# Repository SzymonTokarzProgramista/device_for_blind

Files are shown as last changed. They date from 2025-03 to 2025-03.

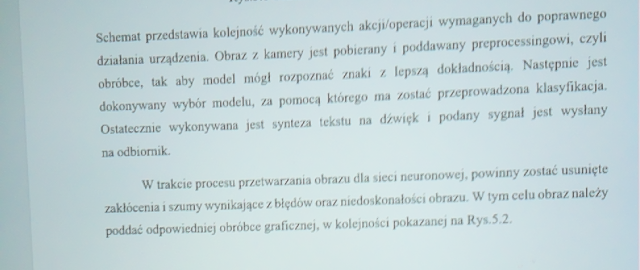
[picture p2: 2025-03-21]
inzynierka/obrona.png

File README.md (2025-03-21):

# device_for_blind
This device is designed to assist visually impaired individuals by recognizing printed characters and converting them into accessible formats (e.g., audio feedback). The system uses a camera to capture text in the environment, then processes the image using two machine learning models for character recognition.

The first model is a custom Convolutional Neural Network (CNN) trained from scratch for basic character classification. The second model leverages ResNet50 with transfer learning, allowing for more accurate and robust recognition, especially in more complex or noisy environments.

By combining these two models, the device ensures both speed and high accuracy in real-time character detection. It is intended to support independence for visually impaired users by helping them interpret written information in their daily lives.

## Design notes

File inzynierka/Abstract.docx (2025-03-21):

Abstract

In his paper, the author described the process of developing the device, starting with presenting the design of the tool. Then the operation of image processing was described, where the various possible filtering and segmentation methods were analyzed and the one that gave the best results was selected. Later, the construction of neural networks was discussed, and it was explained how the model using the author's neural network and the model using ResNet 50 learned with Transfer Learning works. It is also described how both models were implemented on the Raspberry Pi platform along with sound synthesis. Functional tests of the device's performance under various conditions depending on the angle at which the image was taken and the lighting were performed. The author has fulfilled all the objectives outlined in the scope of work, including preparing the design of the case for the device and printing it.

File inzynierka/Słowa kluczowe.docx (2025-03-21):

Słowa kluczowe:

Binaryzacja, filtr Wienera, segmentacja oparta na liniach konturowych, konwolucyjne sieci neuronowe, Transfer learning, rozpoznawanie tekstu, Raspberry Pi, druk 3D, ResNet50, bezprzewodowa komunikacja, Bluetooth, synteza tekstu na dźwięk

Keywords:

Binarization, Wiener filter, contour line based segmentation, convolutional neural networks, Transfer learning, text recognition, Raspberry Pi, 3D printing, ResNet50, wireless communication, Bluetooth, text to sound synthesis

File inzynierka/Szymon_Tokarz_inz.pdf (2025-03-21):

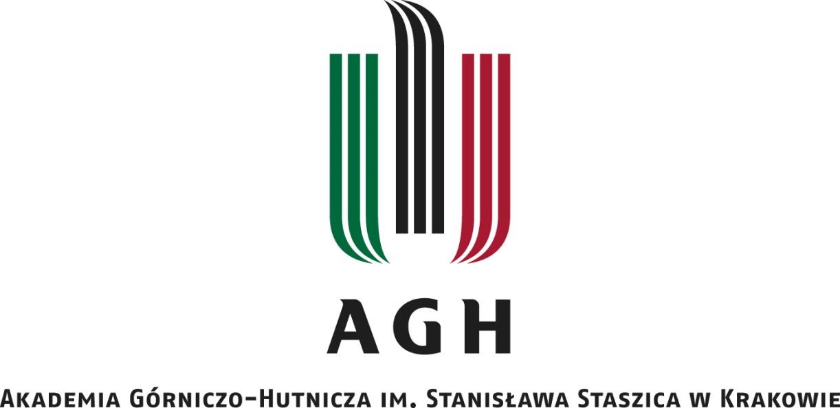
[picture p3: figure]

1

––

WYDZIAŁ ELEKTROTECHNIKI, AUTOMATYKI, INFORMATYKI I INŻYNIERII BIOMEDYCZNEJ

## Projekt dyplomowy

## System wizyjny do odczytu materiałów drukowanych wspomagający osoby niewidzące A vision system for reading printed materials supporting blind people

Autor: | Szymon Tokarz
Kierunek studiów: | Automatyka i Robotyka
Opiekun pracy: | dr inż. Maciej Rosół

Kraków, 2025

2

## Oświadczenie

Świadomy odpowiedzialności karnej za poświadczanie nieprawdy oświadczam, że niniejszą

inżynierską pracę dyplomową wykonałem/łam osobiście i samodzielnie oraz nie

korzystałem/łam ze źródeł innych niż wymienione w pracy.

Jednocześnie oświadczam, że dokumentacja oraz praca nie narusza praw autorskich

w rozumieniu ustawy z dnia 4 lutego 1994 roku o prawie autorskim i prawach pokrewnych

(Dz. U. z 2006 r. Nr 90 poz. 631 z późniejszymi zmianami) oraz dóbr osobistych chronionych

prawem cywilnym. Nie zawiera ona również danych i informacji, które uzyskałem/łam

w sposób niedozwolony.

Zaświadczam także, że niniejsza inżynierska praca dyplomowa nie była wcześniej podstawą

żadnej innej urzędowej procedury związanej z nadawaniem dyplomów wyższej uczelni lub

tytułów zawodowych.

3

## Spis treści

4

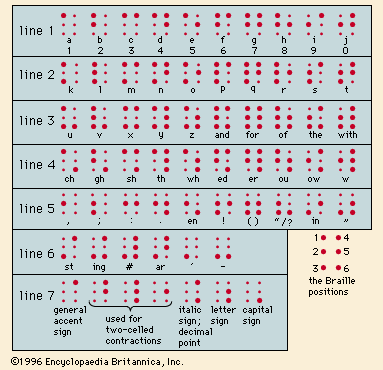
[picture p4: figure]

5

# Rozdział 1 Wstęp [2]

Na przestrzeni ostatnich kilkudziesięciu lat pojawiały się najróżniejsze rozwiązania

mające na celu pomoc osobom niewidzącym w czytaniu. Zdecydowanie najbardziej

popularnym i rozpowszechnionym jest alfabet Braille’a, który wspiera w codziennym życiu

wiele osób niepełnosprawnych. Zastąpienie typowych liter alfabetu zestawem wypukłych

punktów przez Louis Braille’a w 1821 roku umożliwiło niewidomym czytanie i było

największym skokiem w historii ich edukacji. Sam system jest uproszczeniem kodu

wojskowego wymyślonego przez Charlesa Barbiera, który pozwalał na komunikację w nocy

pomiędzy oficerami. Alfabet Braille’a, przedstawiony na rysunku 1.1, składa się z 63 znaków

obejmujących maksymalnie 6 wypukłych kropek ustawionych w macierzy 3x2.

Rys.1.1 Alfabet Braille’a [2]

## 1.1 Cel Pracy

Celem pracy jest projekt i praktyczna realizacja systemu wizyjnego do rozpoznawania

liter i cyfr w języku polskim i angielskim z drukowanych materiałów, służącego jako pomoc

dla osób niewidomych. Rozpoznane litery i słowa będą następnie przekształcane na sygnał

dźwiękowy, który może zostać odsłuchany przez te osoby. Urządzenie to wraz

z oprogramowaniem powinno być łatwe oraz intuicyjne w użyciu.

6

## 1.2 Zakres pracy

Zakres pracy obejmuje zaprojektowanie oraz wykonanie sieci neuronowej służącej

do rozpoznawanie znaków drukowanych, a następnie przekształcenie rozpoznanego ciągu

znaków na sygnał dźwiękowy z możliwością jego odsłuchania. Zadana sieć neuronowa jest

jednokierunkowa oraz może mieć maksymalnie 2 warstwy wewnętrzne. Oczekuje się

przeprowadzania porównania między własnoręczną siecią neuronową, a gotowym modelem,

który za pomocą metody Transfer Learningu został nauczony rozpoznawać znaki. Całe

urządzenie będzie osadzone w obudowie, która zostanie zaprojektowana oraz wydrukowana

przez autora.

Rozdział 1 opisuje podstawowe założenia oraz cele pracy dyplomowej. Opisane są

również przewidywane wyniki pracy dyplomowej, cele i zakres pracy.

W rozdziale 2 autor porusza temat rynku istniejących rozwiązań sprzętowo-

programowych dla osób niewidomych oraz prezentuje wybrane dostępne produkty.

Rozdział 3 opisuje założenia projektowe. Autor przedstawia w nim wybrane podzespoły

wykorzystane w projekcie oraz pokazuje jego wstępną logikę. Autor przedstawia wykonany

przez niego projekt obudowy wraz z koniecznymi rysunkami technicznymi i modelami 3D.

Rozdział 4 wyjaśnia zagadnienia związane z uczeniem maszynowym, które są

wykorzystane w pracy oraz omawia ich zastosowanie.

Rozdział 5 jest poświęcony przygotowaniu obrazu. Autor opisuje i porównuje wybrane

metody filtracji i segmentacji, które mogą zostać wykorzystane w projekcie oraz wybiera

optymalną opcję.

Rozdział 6 jest poświęcony budowie przygotowanej sieci neuronowej oraz wykonanej

bazie danych. Autor porusza w nim tematy z zakresu rodzajów warstw w konwolucyjnych

sieciach neuronowych oraz przytacza wartości hiperparametrów. Opisuje również model

ResNet 50 wykorzystany do Transfer Learningu oraz omawia, jakie modyfikacje zostały

wprowadzone do tej sieci.

W rozdziale 7 przedstawione są rezultaty uzyskane za pomocą obydwóch modeli oraz

zostało przeprowadzone porównanie tych wyników. Autor omawia w nim wady i zalety

wykorzystanych sieci w kontekście problemu opisywanego w pracy.

7

Rozdział 8 omawia etapy złożenia oraz połączenia wszystkich części projektu

opisywanych w pracy. Przedstawione zostają metody implementacji projektu oraz syntezy

tekstu na mowę.

Rozdział 9 opisuje aplikację wykonaną w celu ułatwienia testowania urządzenia.

Poruszane są w nim treści z zakresu narzędzi użytych do tworzenia GUI oraz zalety jego

stworzenia. Przedstawione są testy funkcjonalne urządzenia, które mają na celu sprawdzenie

poprawności działania w różnych warunkach.

8

# Rozdział 2 Przegląd istniejących rozwiązań

Obecnie na rynku istnieje kilka interesujących rozwiązań wspomagających czytanie

i rozumienie tekstu osobom niewidomym, jednak każde z nich ma swoje wady i zalety.

Narzędzia rozpoznające tekst powinna cechować duża dokładność oraz możliwość

identyfikacji znaków drukowanych jak i pisma ręcznego. Problem z dokładnym

sklasyfikowaniem konkretnych liter i cyfr pisma ręcznego sprawia różnorodność charakterów

pisma i nie tylko, ponieważ znaczenie ma również nawet kolor długopisu i strony, który może

powodować zaburzenia odczytu przez urządzenie. Kolejnym ważnym czynnikiem jest cena

produktu. Osoby niepełnosprawne, w tym ludzie niewidomi, mają ograniczony budżet

związany ze swoją przypadłością, więc kwota, którą powinni zapłacić za urządzenie nie

powinna być duża. Jednak z mniejszą ceną naturalnie wiąże się gorsza jakość części

hardware’u, takich jak kamera bądź skaner. Użycie gorszego sprzętu oznacza również

zmniejszoną dokładność rozpoznawania znaków. Z tych względów rynek narzędzi

rozpoznających tekst jest dosyć zróżnicowany.

## 2.1 LyriQ Text-to-Speech Reader [1]

Urządzenie firmy Zyrlo (Rys.2.1), w odróżnieniu od narzędzia wykonanego przez

autora, wykorzystuje skaner w celu zwiększenia dokładności rozpoznawania tekstu. Użycie

skanera powoduje, że LyriQ jest dosyć sporym i relatywnie ciężkim obiektem. Waży około

1,3 kg (3 lbs), ma możliwość złożenia na płasko, co faktycznie ułatwia transport. Najbardziej

odstraszającym czynnikiem w samym produkcie jest niewątpliwie cena, która mieści się w

granciach 2300 – 2500 $, czyli w przeliczeniu na polską walutę to około 9200 – 10000 zł.

Dodatkowo trzeba wziąć pod uwagę koszty wysyłki. Wysoka cena jest spowodowana jakością

produktu. LyriQ Text-to-Speech Reader błyskawicznie rozpoczyna czytanie i jest intuicyjny

w użyciu. Urządzenie wykorzystuje sztuczną inteligencję – Lyriq AI, która jest w stanie

rozpoznać pismo odręczne jak również materiały drukowane takie jak rachunki czy paragony.

Dzięki użyciu skanera dokładność urządzenia Lyriq wynosi około 98%. Posiada także

możliwość skanowania kodów kreskowych. Urządzenie ma możliwość czytania w 20 różnych

językach, domyślnie zainstalowano angielski i hiszpański.

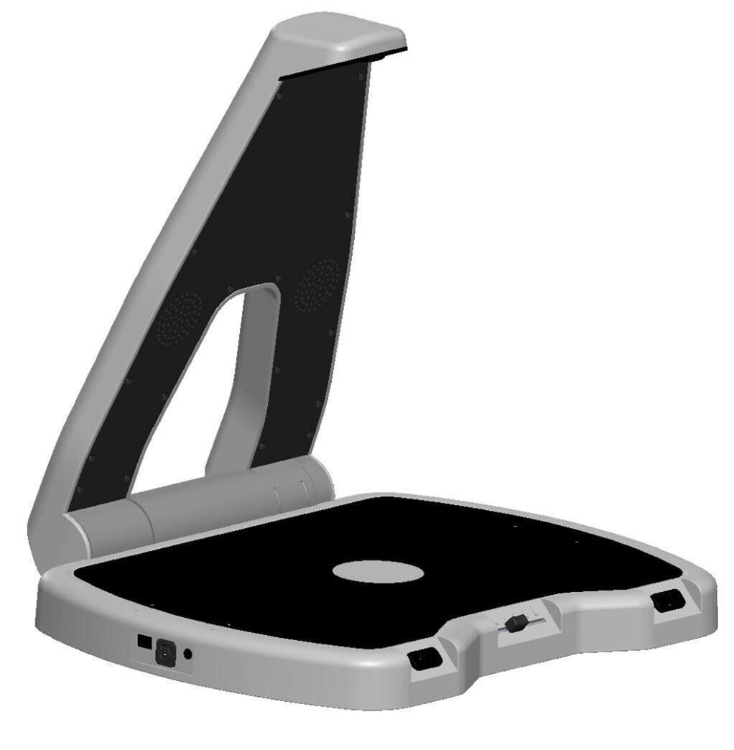
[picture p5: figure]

9

Rys.2.1 Urządzenie LyriQ [1]

## 2.2 Envision Low Vision Glasses [3]

Ciekawym rozwiązaniem są okulary firmy Envision (Rys.2.2). Zaprojektowane z myślą

o komforcie użytkownika, okulary poza rozpoznawaniem teksu zostały wyposażone w szereg

różnych funkcji, takich jak, rozpoznawanie kolorów, skanowanie dokumentów, czy nawet

rozpoznawanie ludzi. Urządzenie zostało zaprojektowane na podstawie Google Glass

Enterprise Edition 2 oraz wyposażone w lekkie tytanowe oprawki. Największą zaletą produktu

firmy Envision jest jego wygoda. Samo urządzenie można zamówić w różnych opcjach, które

oczywiście mają inne ceny w zależności od wyposażonych funkcji. Najbardziej podstawowa

wersja okularów Envsion kosztuje około 8 500 zł. Okulary firmy Envision wykorzystują

sztuczną inteligencję zapewnianą przez Google. Pozwala ona na rozpoznanie tekstu

z dokładnością 95% - 99% w dobrych warunkach oświetleniowych. Urządzenie ma nawet

możliwość połączenia z Chatem GPT-4. Wykorzystano w nim kamerę 8MP z 80º polem

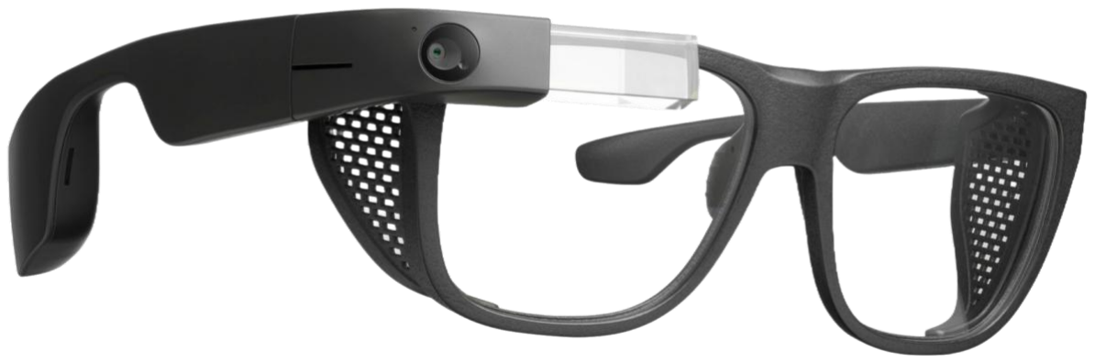
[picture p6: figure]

10

widzenia, które przetwarza obrazy w czasie rzeczywistym, co pozwala na dokładne

rozpoznanie tekstu.

Rys.2.2 Envision Low Vision Glasses [3]

## 2.3 Text to Speech (TTS) [4]

Bardzo popularnym rozwiązaniem jest użycie Text to Speech (TTS). Jest to rozszerzenie

wyprodukowane przez Google wykorzystujące sztuczną inteligencję tej samej firmy.

Wykorzystanie tej wtyczki jest bardzo proste, wystarczy mieć telefon i zrobić zdjęcie strony.

Google zapewnia możliwość czytania w ponad 50 językach operujących na różnych alfabetach.

Narzędzie ma również opcję wyboru lektora. Wtyczka sprawia, że użytkownikowi wystarczy

telefon komórkowy, aby pomóc osobie niewidomej. Google TTS wykorzystuje technologię

WaveNet, stworzoną przez firmę DeepMind, do generacji dźwięku z bardzo naturalnym

brzmieniem.

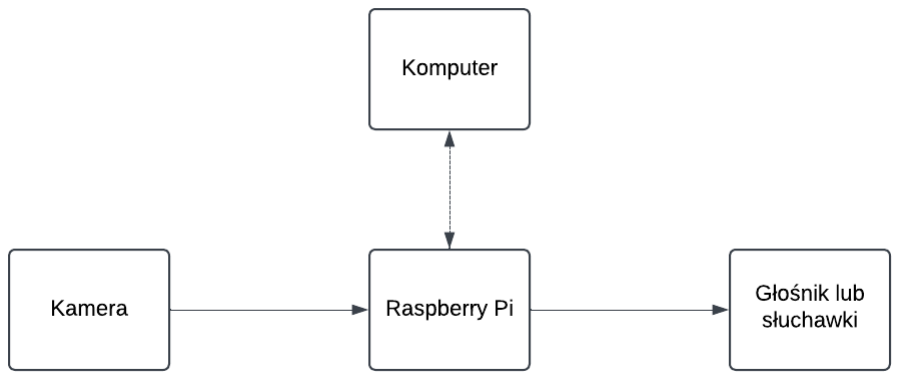
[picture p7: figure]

11

# Rozdział 3 Projekt urządzenia

Jak wspomniano we wstępie, zaproponowane urządzenie wspomagające osoby

niewidzące powinno być tanie i zapewniać prostotę użytkowania. Stąd założenia projektowe

koncentrują się na ogólnodostępnych, budżetowych komponentach. Schemat blokowy

przedstawiający koncepcję budowy urządzenia przedstawiono na Rys.3.1. Zawiera on

minikomputer Raspberry Pi, kamerę, wyjście audio do podłączenia głośników lub słuchawek

oraz komputer klasy PC.

Rys.3.1 Poglądowy schemat blokowy urządzenia

Obraz będzie pobierany z kamery i przesłany na platformę Raspberry Pi, gdzie zostanie

przetworzony oraz klasyfikowany. Raspberry Pi zostanie połączone bezprzewodowo

za pomocą sieci WiFi z komputerem osobistym, gdzie będzie można zobaczyć podgląd

z kamery oraz dokonać wyboru, który typ modelu wykorzystać do klasyfikacji. Rozpoznany

tekst zostanie przekonwertowany na dźwięk i wysłany, za pomocą Bluetooth, do głośnika lub

słuchawek.

## 3.1 Raspberry Pi 4B

Do wykonania urządzenia autor zdecydował się na użycie minikomputera Raspberry Pi

4B (Rys.3.2) ze względu na jego kompaktowość oraz niski koszt. Dodatkową zaletą jest

również możliwość wykorzystania narzędzi w środowisku Matlab/Simulink takich jak,

np. MATLAB Support Package for Raspberry Pi Hardware, które są kompatybilne z platformą

Raspberry Pi i bardzo ułatwiają programowanie urządzenia. Wykorzystano system operacyjny

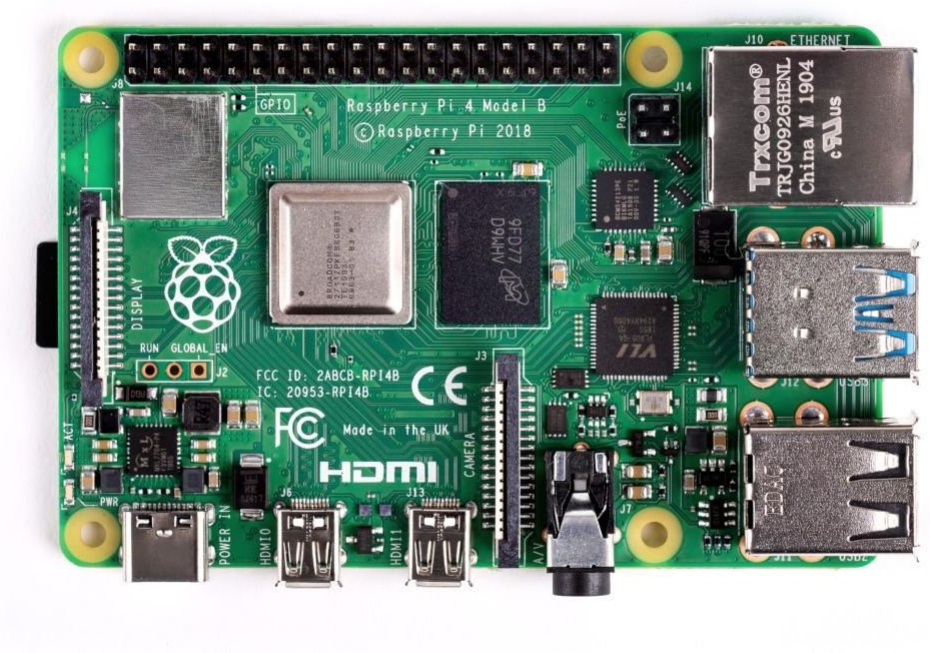
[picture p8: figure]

12

Raspberry Pi OS w wersji bookworm. W tabeli 3.1 zawarto specyfikację techniczną użytej

platformy sprzętowej.

Tabela 3.1 Podstawowe parametry techniczne Raspberry Pi 4B [22]

Procesor | Cortex-A72
Liczba rdzeni | 4
Liczba portów USB 3.0 | 2
Liczba portów USB 2.0 | 2
Liczba portów Gigabit Ethernet | 1
Bluetooth | 5.0
Zasilanie | 5V/3A
RAM | 4GB

Rys.3.2 Raspberry Pi 4B [22]

13

## 3.2 Kamera 5MP OV5647

Do akwizycji obrazów z drukowanych dokumentów tekstowych wybrano kamerę 5MP

OV5647 (Rys.3.3) ze względu na kompatybilność z platformą Raspberry Pi 4B oraz wysoką

jakość obrazu w porównaniu do ceny. Dane techniczne użytej kamery są widoczne w tabeli 3.2.

Tabela 3.2 Dokumentacja kamery 5MP OV5647 [23]

Liczba MP | 5
Aktywne piksele | 2592x1944
Tryby wideo | 1080p30,720p60,640x480p60/90
Ogniskowa | 3,60 mm
FoV | 54x41
Rozmiar piksela | 1,4µm x 1,4µm

Rys.3.3 Kamera 5MP OV5647 [23]

## 3.3 Projekt obudowy

Komponenty użyte do budowy urządzenia zostały umieszczone w zaprojektowanej

obudowie. Na tym etapie użyto program Inventor Professional 2025 firmy Autodesk.

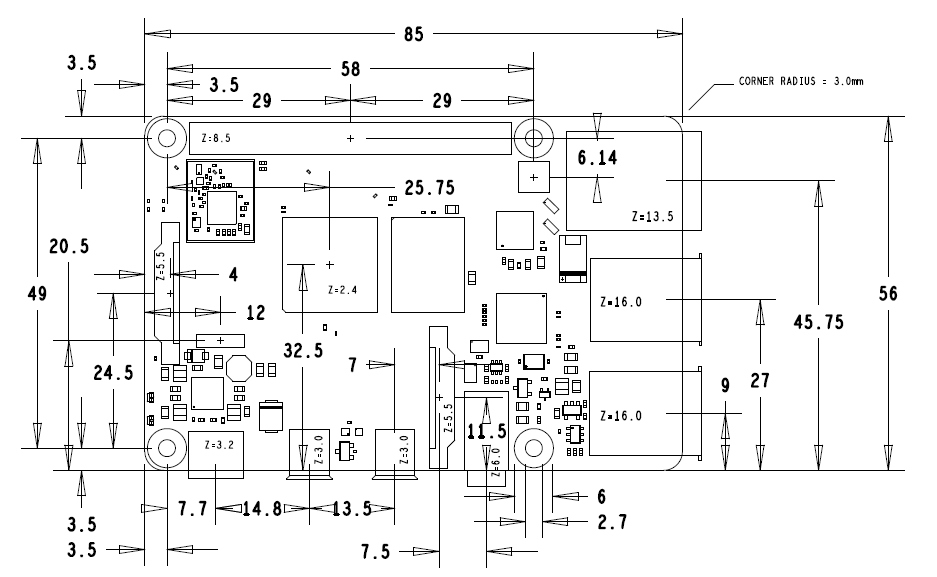
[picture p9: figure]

14

Wykonano w nim model 3D obudowy, który później został użyty do druku 3D. Cała obudowa

składa się z części górnej i dolnej, które zostały połączone śrubami M2,6. Do projektu obudowy

wykorzystano gotowy model 3D Raspberry Pi 4B, który został pobrany ze strony GrabCad

(Rys.3.4) (Rys.3.5).

Rys.3.4 Rysunek techniczny modelu Raspberry Pi 4B [20]

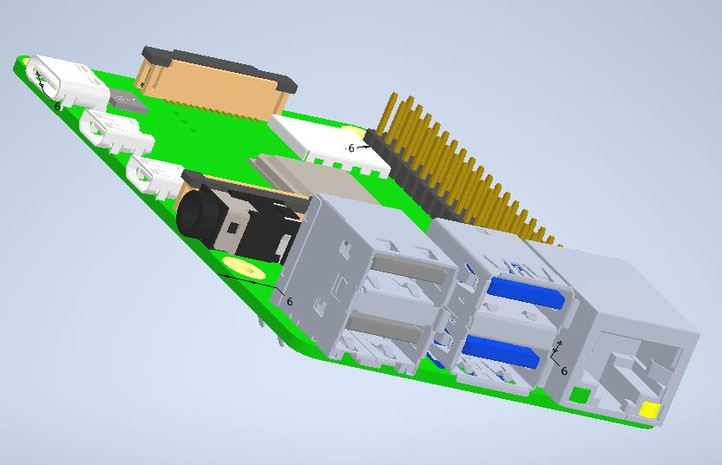
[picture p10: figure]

15

Rys.3.5 Model 3D Raspberry Pi 4B [20]

Po zapoznaniu się z modelem Raspberry Pi i upewnieniu się, że wymiary są poprawne

rozpoczęto projektowanie części obudowy. Wykonane modele części górnej i dolnej wraz

z rysunkami technicznymi (uwzględniającymi model złożeniowy) przedstawiono odpowiednio

na Rys.3.6 i Rys.3.7.

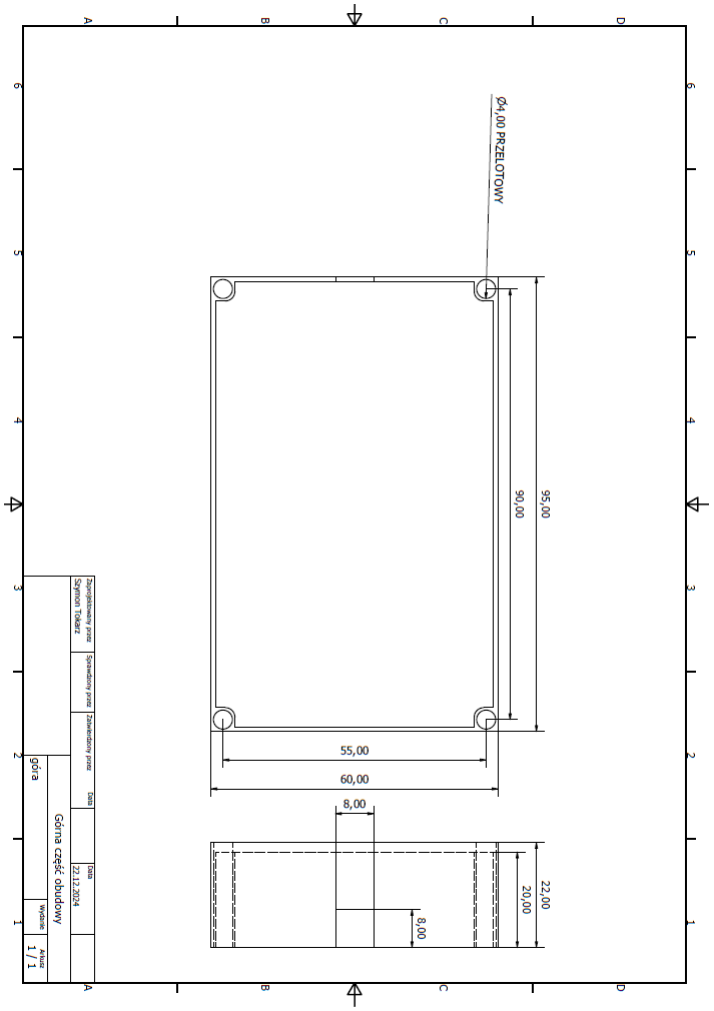
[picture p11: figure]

16

Rys.3.6 Rysunek techniczny górnej części obudowy

17

Rys.3.7 Rysunek techniczny dolnej części obudowy

18

## 3.4 Komputer

W celu wykonania projektu należało wykorzystać komputer osobisty, który został użyty

do zaprogramowania minikomputera Raspberry Pi oraz do przeprowadzenia testów

funkcjonalnych urządzenia. Do napisania kodu programu, obsługującego urządzenie,

wykorzystano głównie środowisko Matlab/Simulink 2024b wraz z następującymi

przybornikami:

- Audio Toolbox,
- Computer Vision Toolbox,
- Deep Learning Toolbox,
- Image Processing Toolbox,

oraz dodatkowe pakiety sprzętowe (ang. Hardware Package) służące do obsługi Raspberry Pi:

- Matlab Support Package For Raspberry Pi Hardware,
- Simulink Support Package For Raspberry Pi Hardware.

W celu stworzenia bazy danych, gromadzącej dane potrzebne do nauki sieci neuronowej, użyto

języka Python 3.9. Jako środowisko rozwojowe tego języka wykorzystano IDE PyCharm

2023.2.2.

Komputer zostanie połączony przez sieć WiFi z urządzeniem i będzie odpowiedzialny

za wybór rodzaju modelu do rozpoznawania tekstu. Stworzona będzie również aplikacja, na

której zostanie wyświetlony aktualny obraz z kamery.

19

# Rozdział 4 Zagadnienia uczenia maszynowego

Uczenie maszynowe (ang. Machine Learning) to dział sztucznej inteligencji, który

polega na tym, że komputery mogą zbierać wiedzę z danych i na ich podstawie rozpoznawać

wzorce [11]. Rozpoznaje się dwa główne rodzaje uczenia maszynowego: nadzorowane

i nienadzorowane. Różnica pomiędzy nimi polega na tym, że w uczeniu nadzorowanym dane

są etykietowane, a w nienadzorowanym nie. Taki zabieg sprawia, że uczenie nadzorowane jest

dokładniejsze i szybsze w treningu, za to przy uczeniu nienadzorowanym można

wykorzystywać niepełne bazy danych.

W uczeniu maszynowym można wykorzystać najróżniejsze algorytmy. Najbardziej

popularne to:

- algorytmy regresyjne,
- algorytmy wykorzystujące drzewa decyzyjne,
- algorytm Bayesa,
- sieci neuronowe.

W dalszej części tego rozdziału zostaną omówione podstawowe zagadnienia, takie jak sieci

neuronowe i Transfer Learning, które to zostały wykorzystane w projekcie.

## 4.1 Sieć neuronowa [7]

„System przeznaczony do przetwarzania informacji, którego budowa i zasada działania

są w pewnym stopniu wzorowane na funkcjonowaniu fragmentów rzeczywistego

(biologicznego) systemu nerwowego. Na przesłankach biologicznych oparte są schematy

sztucznych neuronów wchodzących w skład sieci oraz (w pewnym stopniu) jej struktura.

Jednak schematy połączeń neuronów w sieci neuronowej są wybierane arbitralnie, a nie

stanowią modelu rzeczywistych struktur nerwowych.” [8]

W | kontekście | rozpoznawania | znaków | drukowanych, | sieci neuronowe | są

wykorzystywane już od prawie 30 lat. Pierwszymi, którzy je zastosowali byli Rost i Kwatra

[5][6]. Wytrenowali swoje sieci w celu rozpoznawania angielskich samogłosek. Od tego

momentu informatykom z całego świata udało się zaprogramować sieci neuronowe

20

rozpoznające takie języki jak mandaryński, mongolski, urdu lub nawet staro-cerkiewno-

słowiański z bardzo dużą dokładnością.

Najbardziej popularne sieci neuronowe służące do OCR (ang. Optical Character

Recognition) są kilkuwarstwowe z propagacją wsteczną. Zgodnie z pozycją [8] „Propagacja

wsteczna opiera się na koncepcji poprawiania na każdym kroku procesu uczenia wartości

korekty wag na podstawie oceny błędu popełnianego przez każdy neuron podczas uczenia

sieci”.

## 4.2 Transfer Learning [9]

Transfer Learning jest techniką wykorzystywaną w Machine Learningu polegającą

na ponownym użyciu modelu do zwiększenia jakości lub szybkości rozwiązania dla podobnego

zadania. Definicja brzmi następująco:

Dla dziedziny źródła Ds i zadania uczącego Ts, dziedzina celu Dt i zadania uczącego Tt,

Transfer Learning ma na celu poprawę efektów uczenia funkcji przewidywania celu ft (·)

w dziedzinie Dt wykorzystując wiedzę w dziedzinie Ds i zadaniu Ts, gdzie Ds ≠ Dt oraz

Ts ≠ Tt.[9][10]

W swojej pracy Pan i Yang dzielą Transfer Learning na 3 rodzaje (Tabela 4.1):

- indukcyjny,
- nienadzorowany,
- transdukcyjny.

Tabela 4.1 Rodzaje Transfer Learningu [9]

Ustawienia uczenia | Dziedzina źródła i celu | Zadanie źródła i celu
Tradycyjny Machine Learning | Taka sama | Takie same
Transfer Learning | Indukcyjny | Taka sama | Inne, ale spokrewnione
| Nienadzorowany | Inna, ale spokrewniona | Inna, ale spokrewnione
| Transdukcyjny | Inna, ale spokrewniona | Takie same

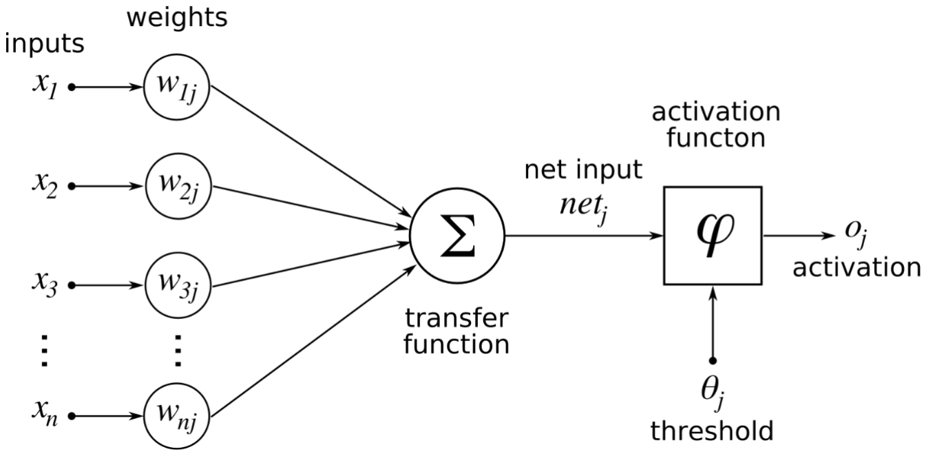
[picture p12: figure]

21

Obecnie Transfer Learning jest wykorzystywany głównie przy analizie tekstu oraz

obrazów ze względu na łatwość w implementacji, jakość prezentowanych rozwiązań oraz brak

potrzeby dużej bazy danych. Kolejną zaletą Transfer Learningu jest fakt, że istnieje szeroki

wachlarz wytrenowanych sieci neuronowych, które można wykorzystać jako źródło.

## 4.3 Konwolucyjne sieci neuronowe (CNN) [24]

Konwolucyjna sieć neuronowa jest przykładem sieci typu feed forward, co oznacza, że dane

przepływają tylko w jednym kierunku. Typowe sieci CNN składają się z różnych rodzajów

warstw, jak np.:

- warstwa konwolucji,
- warstwa aktywacji,
- warstwa poolingu,
- warstwa w pełni połączona (ang. fully connected layer).

Sieć CNN składa się z połączenia kilku warstw konwolucyjnych, po których znajduje się

warstwa poolingu powtórzona kilkukrotnie. Na samym końcu znajduje się warstwa w pełni

połączona. Architekturę takiej sieci przedstawiono na rysunku 4.1. Dokładny opis

poszczególnych warstw sieci CNN, wykorzystanej w pracy, znajduje się w rozdziale 6.

Rys.4.1 Schemat sieci konwolucyjnej [25]

22

# Rozdział 5 Proces przetwarzania obrazu

Program uruchamiany na platformie Raspberry Pi uwzględnia wszystkie etapy

od pobrania obrazu z kamery do syntezy dźwięku na podstawie rozpoznanego tekstu. Schemat

blokowy logiki programu przedstawiono na Rys.5.1.

Rys.5.1 Schemat blokowy logiki programu

Schemat przedstawia kolejność wykonywanych akcji/operacji wymaganych do poprawnego

działania urządzenia. Obraz z kamery jest pobierany i poddawany preprocessingowi, czyli

obróbce, tak aby model mógł rozpoznać znaki z lepszą dokładnością. Następnie jest

dokonywany wybór modelu, za pomocą którego ma zostać przeprowadzona klasyfikacja.

Ostatecznie wykonywana jest synteza tekstu na dźwięk i podany sygnał jest wysłany

na odbiornik.

W trakcie procesu przetwarzania obrazu dla sieci neuronowej, powinny zostać usunięte

zakłócenia i szumy wynikające z błędów oraz niedoskonałości obrazu. W tym celu obraz należy

poddać odpowiedniej obróbce graficznej, w kolejności pokazanej na Rys.5.2.

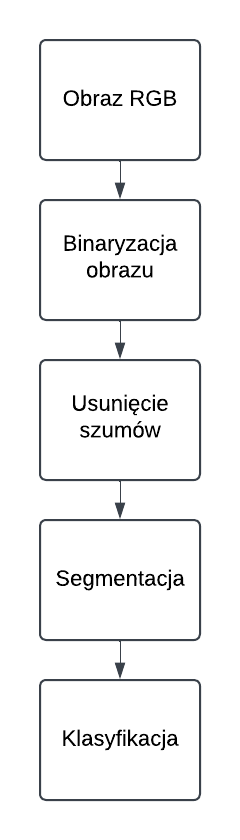
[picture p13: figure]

23

Rys.5.2 Schemat blokowy dla przetwarzania obrazów

Najpierw obraz RGB musi zostać poddany binaryzacji, czyli konwersji do reprezentacji

czarno-białej. Następnym etapem jest usunięcie szumów. Proces polega na analizie obrazu

binarnego i znalezieniu pikseli, które nie pasują do ich otoczenia. Na Rys.5.3 widać,

że kilkanaście pikseli nie należy do liter, ale istnieją w obrazie. Piksele te trzeba usunąć,

ponieważ zaburzają klasyfikację sieci neuronowej. Kolejną etapem jest odpowiednia

segmentacja obrazu na poszczególne litery. Ostatnim krokiem jest klasyfikacja obrazu

do odpowiedniej litery.

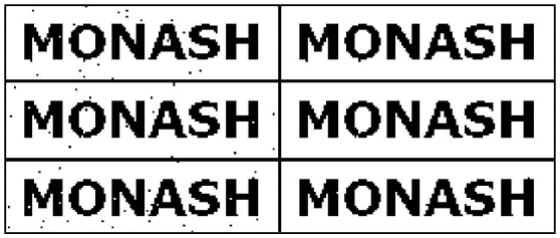
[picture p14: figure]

24

Rys.5.3 Przykład usuwania szumów [7]

## 5.1 Obraz RGB i binaryzacja

Urządzenie jest obsługiwane przez kamerę o rozdzielczości 5 MP, więc obraz może być

nieznacznie zamazany. W tym celu, aby uzyskać jak najlepszą binaryzację całego obrazu, autor

najpierw przekształca go do odcieni szarości, po czym dokonuje korekcji kontrastu (Rys.5.4).

Dzięki temu zabiegowi łatwiej jest dobrać uniwersalny próg binaryzacji, ponieważ różnice

pomiędzy tłem, a tekstem są zdecydowanie większe. Przeprowadzenie binaryzacji jest

konieczne, ponieważ ułatwia analizę obrazu przez sieć neuronową. Użycie tej operacji

zwiększa dokładność i szybkość klasyfikacji.

25

Rys.5.4 Operacje przeprowadzone na obrazie

## 5.2 Filtracja i usuwanie szumów [12]

Po binaryzacji obrazu należy przefiltrować go ze względu na występujące szumy.

W tym celu autor rozważał użycie następujących filtrów:

- filtr uśredniający,
- filtr medianowy,
- filtr Wienera,
- filtr korzystający z operacji morfologicznych.

Filtr uśredniający poprawia wartość piksela na podstawie średniej wartości pikseli

w jego otoczeniu. Rxy reprezentuje sąsiedztwo okna podobrazu o wymiarach m × n, o środku

w punkcie (x, y). Dla poziomu szarości piksela (x, y), filtr zmienia poziom szarości J(x, y)

ze szczegółami otaczającego piksela. Opisuje to równanie:

26

J(x, y) =

1
M ⋅ N

∑ K(u, v)

(u,v)∈Rxy

Filtr medianowy jest nieliniową metodą wykorzystującą wartość mediany wartości

szarości otaczających pikseli. Ten filtr jest w stanie usunąć zaburzenia bez rozmazywania

krawędzi. Mediana jest obliczana po posortowaniu wartości pikseli i wybierana jest z nich

środkowa wartość. Filtr może wybierać różne rozmiary otoczenia, jednak najbardziej popularne

są 3 × 3 lub 5 × 5. Filtr ten jest zdefiniowany równaniem:

J(x, y) = median(u,v)∈Rxy

{K(u, v)}

Filtr Wienera jest przykładem adaptacyjnego filtru, który działa w oparciu

o minimalizację błędu średniokwadratowego (MSE). Jego zaletą jest lepsze działanie niż np.

filtr średniej zwłaszcza w obszarach o zróżnicowanej intensywności, jednak wymaga

większego nakładu czasowego. Równanie opisujące filtr Wienera ma następującą postać:

I

̂(x, y) =

σI

2

σI

2+σN

2

⋅ I(x, y),

gdzie:

- I

̂(x, y): Wyjściowy (oczyszczony) obraz,

- I(x, y): Sygnał wejściowy z szumem,
- σI

2
: Wariancja obrazu oryginalnego,
- σN

2
: Wariancja szumu.

Istnieje również możliwość przefiltrowania obrazu działając wyłącznie na operacjach

morfologicznych. Wymaga to użycia funkcji bwareaopen, która jest dostępna w pakiecie Image

Processing Toolbox programu MATLAB. Ta funkcja znajduje obiekty o rozmiarach zadanych

jako argument i je usuwa. Tę operację należy wykonać na obrazie binarnym oraz trzeba zadać

stały próg wielkości obiektów. Ta metoda jest bardzo użyteczna przy obrazach, na których

występują litery o dużym rozmiarze i nie nachodzą na siebie, ponieważ bezpośrednio usuwa

niechciane artefakty. Wykorzystanie funkcji bwareaopen posiada wadę w postaci długiego

czasu wykonania, spowodowanego skomplikowanym algorytmem.

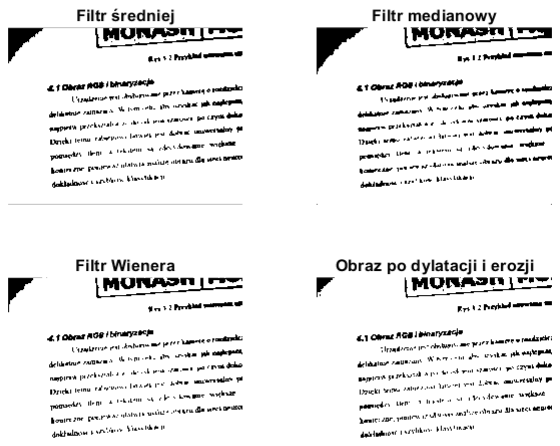
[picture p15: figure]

27

Autor pracy wykonał porównanie rezultatów po filtracji (Rys. 5.5) oraz przeprowadził

testy czasowe w celu wybrania najlepszej opcji dla problemu rozpoznawania znaków

drukowanych.

Rys.5.5 Obrazy po różnych rodzajach filtracji

Z powyższych obrazów można zauważyć, że filtr Wienera daje najlepsze rezultaty

pod względem wyglądu obrazu. Usunął więcej małych artefaktów u góry obrazu, przy czym

nie zniekształcił znacząco liter. Warto zauważyć, że bardzo dobry wynik daje również użycie

funkcji bwareaopen. Przy dużych literach właśnie użycie tej metody najlepiej wyodrębnia

litery. Wyniki testów czasu wykonywania poszczególnych algorytmów filtracji przedstawiono

w Tabeli 5.1.

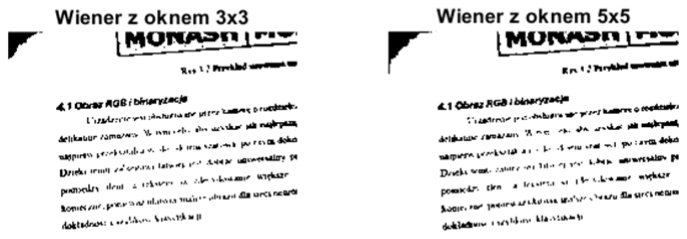
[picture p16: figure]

28

Tabela 5.1 Porównanie testów czasowych

Rodzaj filtru | Średni czas przetwarzania obrazu [s]
Filtr średniej | 0.2673
Filtr medianowy | 0.3246
Filtr Wienera | 0.4625
Funkcja bwareaopen | 3.1932

Czasy potrzebne do przefiltrowania obrazu (Tabela 5.1) są porównywalne dla filtrów

średniej, medianowego i Wienera. Jak przewidywano funkcja bwareaopen zajmuje dużo więcej

czasu, aby wykonać to zadanie. Biorąc pod uwagę testy czasowe oraz dokładność filtracji autor

zdecydował się użyć filtru Wienera.

Należy również dokonać wyboru rozmiaru okna używanego przez filtr Wienera.

Wszystkie poprzednie testy wykonano dla rozmiaru okna 3 × 3 (tak samo, jak dla filtru

medianowego). Analizie poddano trzy rodzaje okien:

- Małe - 3×3, 5×5;
- Średnie - 7×7, 9×9;
- Duże - 15×15, 21×21.

Rys.5.6 Obrazy przy użyciu małych okien dla filtra Wienera

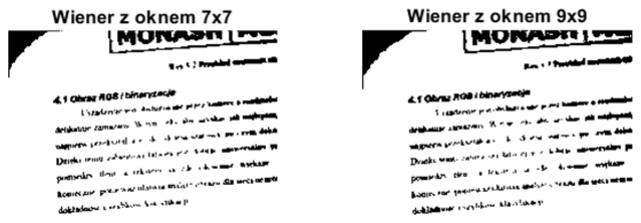
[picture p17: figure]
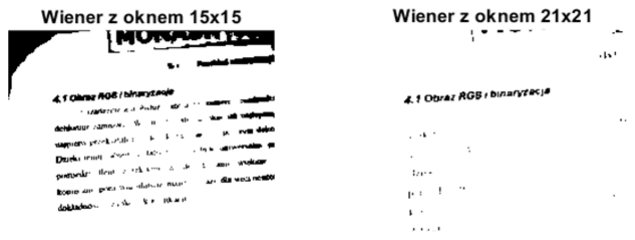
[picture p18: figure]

29

Rys.5.7 Obrazy przy użyciu średnich okien dla filtra Wienera

Rys.5.8 Obrazy przy użyciu dużych okien dla filtra Wienera

Z obrazów przedstawionych na: Rys.5.6, Rys.5.7 i Rys.5.8 można wywnioskować,

że duże okna 15×15 i 21×21, ze względu na swój rozmiar, filtrują zbyt dużą część obrazu.

Z kolei filtry o średnich oknach dobrze usuwają małe obiekty, które nie powinny być poddane

ocenie, ale zbytnio zniekształcają krawędzie liter. Najlepszym rozwiązaniem będzie użycie

okna o wymiarach 5×5, ze względu na lepszą zdolność usuwania niepożądanych szumów niż

okno 3×3 przy zachowaniu odporności na zmianę wyglądu liter.

## 5.3 Segmentacja

Po wstępnej obróbce obrazu należy rozpoznać znajdujący się na nim tekst

z uwzględnieniem podziału na pojedyncze litery, tak aby sieć neuronowa mogła

30

je sklasyfikować. Istnieją różne metody segmentacji, jednak przy rozpoznawaniu tekstu

najbardziej popularne to [26]:

- segmentacja oparta na progowaniu,
- segmentacja oparta na połączeniu pikseli,
- segmentacja oparta na liniach konturowych,
- segmentacja oparta na projekcjach, itd.

Segmentacja oparta na progowaniu jest techniką wykorzystywaną ze względu na swoją

prostotę i łatwość w implementacji, często przy obrazach z małą entropią. Ta metoda dzieli

obraz na regiony na podstawie wartości pikseli w skali szarości. Wartość progu może być

wybrana automatycznie, np. za pomocą funkcji graythresh w środowisku MATLAB, która

wykorzystuje metodę Otsu. Ten algorytm opiera się na wyborze optymalnego progu

na podstawie maksymalizacji wariancji pomiędzy klasami obrazu. Sama metoda może być

zaimplementowana globalnie, gdzie separowane jest tło i cały obraz zostaje podzielony na dwa

regiony. Znacznie bardziej efektywną metodą jest zastosowanie lokalnego progowania, gdzie

progi są wybierane dla poszczególnych części obrazu z wykorzystaniem metody Otsu. Można

również dobrać próg ręcznie.[13]

Algorytm polegający na łączeniu pikseli (ang. Connected Component Labeling) opiera

się na zasadzie mówiącej, że piksele można nazwać połączonymi, gdy spełniają założenia

przylegania albo bliskości piksela. Każdy piksel z połączeniem jest przylegający, ponieważ ma

relację z sąsiadem. Ponadto istnieje także stałość pomiędzy pikselami przylegającymi, która

wynosi 1 jednostkę długości bez żadnego pośrednika. Tą metodę można wykorzystywać przy

obrazach monochromatycznych jak i binarnych. [14]

Segmentacja wykorzystująca detekcję krawędzi polega na analizie zestawu pikseli,

gdzie otaczające go piksele w skali szarości lub zmiany struktury sugerują zmianę regionu.

Krawędź obiektu w obrazie jest odzwierciedlona poprzez różnice w skali szarości, więc

pierwszym krokiem w tym algorytmie jest znalezienie punktów, które utworzą kontur regionu.

Istotą działania tej metody jest wykrywanie nieciągłości w różnych częściach obrazu za pomocą

operatorów różnicowych pierwszego lub drugiego rzędu. [15]

Segmentacja oparta na projekcjach to technika wykorzystująca tzw. „projekcje obrazu”,

czyli sumy wartości pikseli. Ta metoda może wystąpić w dwóch wariantach działający na tej

31

samej zasadzie. Projekcje poziome wykorzystują sumy pikseli z poszczególnych wierszy, za to

projekcje pionowe wykorzystują sumy pojawiające się w kolumnach. Ideą tego algorytmu jest

sprowadzenie informacji do jednowymiarowych profili, które ułatwiają odnalezienie konturów

obiektów. [16]

W ramach pracy wykonano porównanie powyższych metod, w celu wybrania

najlepszego rozwiązania dla poruszanego problemu. Samo porównanie obejmuje jakość

dokonanej segmentacji oraz szybkość działania algorytmu.

Rys.5.9 Segmentacja oparta na progowaniu

Rys.5.10 Segmentacja oparta na łączeniu pikseli

Rys.5.11 Segmentacja oparta na liniach konturowych

Rys.5.12 Segmentacja oparta o projekcje pionowe

Największym problemem w skuteczności działania ww. algorytmów jest fakt, że litery,

w szczególności te małe, mogą nachodzić na siebie, co powoduje, że przy segmentacji często

pojawia się kilka liter w wyodrębnionym fragmencie. Można zaobserwować to zachowanie

przy segmentacji polegającej na progowaniu (Rys.5.9) i łączeniu pikseli (Rys.5.10). Obydwie

metody dają podobne rezultaty, ponieważ wykorzystano w nich do wyznaczenia progu metodę

Otsu. Algorytm używający projekcji (Rys.5.12) nie jest w stanie dobrze podzielić obrazu,

ze względu na jego zbyt słabą jakość i niewielki odstęp pomiędzy literami. Najlepszą

segmentację udało się uzyskać korzystając z algorytmu opartego na liniach konturowych

(Rys.5.11), który poprawnie rozdzielił wszystkie litery w obrazie testowym.

32

Tabela 5.2 Porównanie testów czasowych

Rodzaj segmentacji | Średni czas przetwarzania obrazu [s]
Progowanie | 0.1821
Łączenie pikseli | 0.2075
Linie konturowe | 0.2625
Projekcje | 0.1772

Wyniki czasu wykonania poszczególnych algorytmów segmentacji zebrano

w Tabeli 5.2. Na ich podstawie można stwierdzić, że najlepiej wypadł algorytm

wykorzystujący projekcje, a najgorzej ten oparty o linie konturowe. Jednakże biorąc pod uwagę

dokładność wszystkich metod autor zdecydował się wybrać segmentacje opartą o linie

konturowe.

Przy użyciu tej metody segmentacji należy zadbać o to, aby znaki interpunkcyjne nie

zostały poddane klasyfikacji. Nie wystarczy jedynie nie brać ich pod uwagę jako małych

obiektów, ponieważ w tym wypadku usunięte zostałyby również części znaków „ó”, „ż” oraz

„ź”. W tym celu wykorzystano dylatację, aby połączyć znaki diakrytyczne (np. kropka na „i”)

z resztą litery w jeden region.

33

# Rozdział 6 Klasyfikacja za pomocą sieci neuronowej

Ostatnim etapem rozpoznawania tekstu jest sklasyfikowanie poszczególnych liter oraz

ich połączenie w słowa. Jednakże, aby móc odpowiednio rozpoznać znaki należy przygotować

sieć neuronową. Dokładny opis i definicję, czym jest sieć neuronowa, znajduje się w rozdziale

4.1. W tym rozdziale autor skupi się na opisie budowy, uczenia i testów zaproponowanej sieci

oraz wyjaśni działania wybranych funkcji i parametrów.

## 6.1 Baza danych

W celu wytrenowania sieci neuronowej należało wykorzystać gotową bazę danych lub

przygotować własną. Autor postanowił wykonać samodzielnie bazę danych ze względu na brak

odpowiedniej, która byłaby zgodna z narzuconymi kryteriami. W tym celu przygotowano

skrypt w języku Python, który generował litery polskiego alfabetu i cyfry używając czcionki

Times New Roman, grupował je oraz przygotował osobny plik, gdzie każdy obraz był

skategoryzowany. Zadbano również, aby obrazy były poddane odpowiedniej augmentacji,

co oznacza, że litery były losowo obracane o kąt ± 15º oraz pogrubiane (Rys.6.1). Ten zabieg

sprawia, że zbiór danych jest bardziej zróżnicowany, przez co sieć neuronowa lepiej rozpoznaje

cechy danego obrazu.

Rys.6.1 Przykłady liter z przygotowanej bazy danych

W efekcie podjętych działań uzyskano zbiór 32 znaków (dużych i małych), przy czym

każdy znak alfabetu był reprezentowany w liczbie 5000. Cała baza danych została podzielona

na 3 zbiory:

34

- uczący (80%),
- walidacyjny (10%),
- testowy (10%).

Zbiór uczący był wykorzystany do wytrenowania modelu, walidacyjny do oceny jakości

modelu w trakcie procesu trenowania. Zbiór testowy został użyty po treningu, aby ocenić

ogólną wydajność modelu.

## 6.2 Budowa sieci neuronowej

Do wykonania sieci neuronowej zostało wykorzystane narzędzie Deep Network

Designer, które jest dostępne w Deep Learning Toolbox programu MATLAB. Deep Network

Designer to aplikacja, w której można tworzyć blokowe schematy sieci neuronowych. W tym

celu można wykorzystać gotowe funkcje służące do np. optymalizacji lub normalizacji sieci.

Autor wybrał to narzędzie ze względu na prostotę w obsłudze oraz łatwość implementacji

wybranej struktury sieci neuronowej. Na Rys.6.2 przedstawiono schemat blokowy

zaprojektowanej, konwolucyjnej sieci neuronowej (CNN). Na wejście sieci podawany jest

obraz o wymiarach 28×28 jednokanałowy, czyli binarny. Sama sieć składa się z dwóch warstw

konwolucyjnych, zgodnie z założeniami projektu dyplomowego. Każda warstwa składa się z:

- warstwy normalizacji batcha,
- warstwy aktywacji ReLu,
- warstwy dropout,
- warstwy poolingu 2D.

Warstwa normalizacji batcha jest używana w głębokich sieciach neuronowych ze względu

na przyspieszenie procesu uczenia, stabilizacji gradientów oraz zmniejszenie szansy

na przeuczenie (ang. overfitting). Normalizacja sprawia, że dla każdej partii (ang. batch) każda

cecha ma średnią równą 0 i odchylenie standardowe równe 1, zgodnie z poniższym wzorem:

x̂ =

x − μ
√σ
2 + ϵ

gdzie:

- x̂ to znormalizowana wartość cechy,
- x to pojedyncza wartość wejściowa,

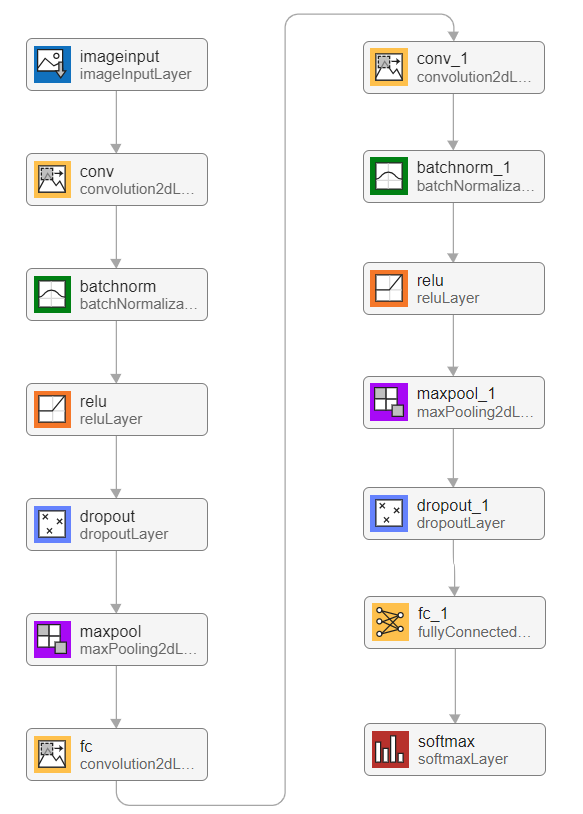
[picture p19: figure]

35

- μ to średnia arytmetyczna wartości wejściowych,
- σ

2
to wariancja wartości wejściowych
- ε to bardzo mała liczba dodawana do mianownika, aby uniknąć dzielenia przez 0.

Rys. 6.2 Schemat blokowy sieci neuronowej

36

Warstwa ReLu (ang. Rectified Linear Unit) to funkcja aktywacji mająca na celu

wprowadzenie nieliniowości, aby model mógł nauczyć się bardziej złożonych zależności. Sama

funkcja jest definiowa jako:

f(x) = max(0, x)

Funkcja ReLu jest bardzo popularna ze względu na łatwość w implementacji, szybkość

działania oraz jest odporna na problem zanikających gradientów.

Warstwa dropout sprawia, że neurony zostają losowo wyłączane, czyli ich wartość

zostaje ustawiana na 0, w celu ograniczenia przeuczenia. Dzięki użyciu tej warstwy sieć nie

polega na zbyt małej liczbie neuronów, przez co model nie jest zależny od pojedynczych cech,

co powoduje lepszą generalizację. Wartość parametru dropout użytego w powyższej sieci

wynosi 0,5, czyli 50% neuronów zostaje wyłączonych.

Warstwa MaxPooling2D pozwala na zmniejszenie wymiarowości danych wejściowych.

Operacja działa na zasadzie maksymalnej selekcji w małych regionach obrazu, czyli wybierana

jest największa wartość w danym oknie. Dzięki tej funkcji model jest w stanie uczyć się

szybciej, przez mniejszą ilość danych oraz jest bardziej odporny na przeuczenie. Wielkość okna

dla funkcji maxPooling2D wynosi 5×5, a krok o jaki przesuwane jest okno to (1,1).

Kluczową częścią wybranej sieci neuronowej są warstwy konwolucyjne, które

odpowiadają za wykrywanie cech. Warstwa konwolucyjna przesuwa filtry, które są małymi

macierzami po całym obrazie. Przy każdym przesunięciu filtr dokonuje operacji splotu, której

wynik jest dodawany do macierzy cech. [17] W pierwszej warstwie przygotowanej sieci

znajdują się 32 filtry o rozmiarze 3×3, które są przesuwane o krok (1,1), natomiast w drugiej

są 64 filtry o wymiarach 5×5, które przemieszczają się z tym samym krokiem. Taki zabieg

powoduje, że model łatwiej jest w stanie rozpoznać bardziej złożone cechy oraz pozwala mu

na bardziej szczegółową analizę danych wejściowych.

Na sam koniec działania sieci dane są analizowane przez warstwę Softmax. Jej zadaniem

jest przekształcanie surowych wyników z wyjścia sieci w rozkład prawdopodobieństwa, który

będzie sumował wartości wszystkich klas do 1. Wzór tej warstwy wygląda następująco:

pi =

e

zi
∑ | e
K | zj
j=1

37

gdzie:

- zi
to logit, czyli surowy wynik, dla klasy i,
- K to liczba klas,
- e

zj
to eksponenta logitu,
- pi prawdopodobieństwo dla klasy i.

Warstwę Softmax wykorzystuje się jako warstwę wyjściową ze względu na możliwość

interpretacji rozkładu prawdopodobieństwa do klasyfikacji obrazu. Na podstawie tej warstwy

można jednoznacznie wskazać, która klasa ma największą szansę na poprawną klasyfikację.

## 6.3 Budowa ResNet50

Istotą Transfer Learningu jest douczenie już wytrenowanej sieci, co dokładniej autor

opisuje w rozdziale 3.2. Kluczowym aspektem staje się wybór odpowiedniej sieci neuronowej.

Autor postanowił wybrać sieć ResNet50 ze względu na jej popularność i zastosowanie

w dziedzinie detekcji obiektów. W środowisku MATLAB istnieje gotowa funkcja rozpoznająca

tekst (ocr ()), która bazuje na silniku Tesseract OCR (open-source), obsługującym ponad 100

języków, w tym polski. Sam silnik jest wspierany przez Google.

ResNet50 to głęboka sieć neuronowa z rodziny Residual Networks, składająca się z 50

warstw konwolucyjnych połączonych za pomocą bloków resztkowych (Rys.6.3). Te bloki

wykorzystują tzw. shortcut connections, co unika problemu zanikającego gradientu,

spowodowanego przez dużą liczbę warstw. Architektura sieci ResNet50 jest podzielona na

4 sekcje:

- warstwy konwolucyjne,
- blok tożsamościowy (ang. identity block),
- blok konwolucyjny,
- w pełni połączone warstwy (ang. fully connected layers).

Warstwy konwolucyjne odpowiadają za ekstrakcje cech z obrazu wejściowego, a bloki

tożsamościowe i konwolucji przetwarzają i przekształcają te cechy. Do klasyfikacji

wykorzystane są w pełni połączone warstwy. [18 - 19]

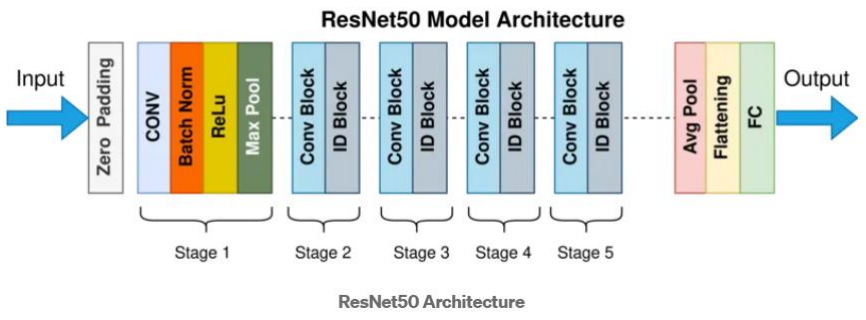
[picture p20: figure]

38

Rys.6.3 Architektura sieci ResNet 50 [19]

Najbardziej kluczowym aspektem sieci z rodziny ResNet jest wykorzystanie tzw.

shortcut connections. Te połączenia pozwalają danym przemieszczać się po sieci

z pominięciem kilku warstw. Ten zabieg umożliwia sieci nauczenie się funkcji resztkowych,

które mapują dane wejściowe, zamiast uczenie się mapowania od zera. Shortcut connections są

używane w blokach konwolucyjnych i tożsamościowych. [19]

## 6.4 Modyfikacja sieci ResNet50

W celu wykorzystania metody Transfer Learningu należało zmodyfikować sieć

ResNet50. Na początku zmodyfikowano dane wejściowe, ponieważ ta sieć wymaga, aby były

one rozmiaru 224×224 oraz wyrażone w kolorach RGB. Po tym zabiegu usunięto ostatnią

warstwę i zastąpiono ją nową, służącą do klasyfikacji, tak aby zgadzała się w niej liczba klas.

Model jest zdecydowanie bardziej skomplikowany niż przygotowana sieć neuronowa

z poprzedniego rozdziału, więc autor zdecydował, aby trenować sieć ustalając mniejszą liczbę

epok.

39

# Rozdział 7 Implementacja programu w Raspberry Pi

Zaimplementowano obydwa modele rozpoznawania tekstu, obsługę kamery oraz

algorytmu przetwarzania obrazu, czyli binaryzację, filtrację oraz segmentację. Cały program

został podzielony na odpowiednie funkcje obsługujące poszczególne zadania.

Ostatnim etapem było zaprogramowanie funkcjonalności, która pozwoli urządzeniu

komunikować się poprzez Bluetooth ze słuchawkami bądź głośnikiem, zaimplementowanie

całego programu na platformę Raspberry Pi oraz złożenie obudowy.

W celu zapewnienia konwersji tekstu na dźwięk użyto najpierw syntezatora mowy

espeak. Narzędzie espeak jest bardzo wygodną opcją ze względu na fakt, że jest darmowe oraz

działa na wielu platformach, w tym na Raspberry Pi. Obsługuje ponad 50 języków i dialektów

oraz ma możliwość dostosowania tempa i tonu głosu. Przygotowano również skrypt

w programie MATLAB, który pozwala na automatyczne parowanie urządzeń z Bluetooth, aby

można było usłyszeć rozpoznawany tekst.

Cały program został podzielony na funkcje, które ułatwiły wykonanie diagramu

blokowego w programie Simulink (Rys.7.1). Jak można zauważyć pierwszym blokiem

w łańcuchu jest blok odczytu obrazu z kamery w formacie RGB. Następnie obraz RGB jest

odczytywany przez blok GUI, gdzie jest przedstawiany użytkownikowi. Użytkownik ma

możliwość zrobienia zdjęcia i wyboru modelu, który przeprowadzi rozpoznawanie tekstu. Gdy

to się wydarzy przeprowadzany jest proces przetwarzania obrazu w bloku preprocessing, gdzie

dokonywana jest filtracja filtrem Wienera oraz segmentacja za pomocą metody używającej linie

konturowe. Zbiór obrazów jest klasyfikowany przez funkcję ocr_1 i ocr_2. Ostatecznie

wykonywana jest konwersja tekstu na dźwięk w bloku speak i następuje wysłanie komunikatu

do urządzenia audio.

Rys.7.1 Schemat blokowy wykonany w Simulinku

40

Na podstawie ww. diagramu wygenerowano kod języka C++, który został przesłany,

skompilowany i uruchomiony na minikomputerze. Użyto do tego przybornika Simulink

Support Package for Raspberry Pi.

Na platformie Raspberry Pi, w celu poprawy wydajności urządzenia, wykorzystano

możliwość użycia większej liczby rdzeni. Dzięki tej metodzie można dokonać równoległej

klasyfikacji obrazów. Wykorzystany minikomputer Raspberry Pi 4B posiada 4 rdzenie, a do

klasyfikacji użyto dwóch. W tym celu zbiór obrazów otrzymanych po segmentacji podzielono

na dwie części. Użyto opcji Concurrent Execution i zmapowano funkcję ocr_1 i ocr_2

do dwóch różnych tasków. Funkcja connect łączy w jeden spójny tekst wyniki klasyfikacji

i zapewnia, że są połączone w odpowiedniej kolejności.

Ostatnim etapem projektu było zamontowanie w obudowie minikomputera Raspberry

Pi wraz z kamerą. Końcowy wygląd urządzenia można zobaczyć na rysunku 7.2.

Rys.7.2 Końcowy wygląd urządzenia

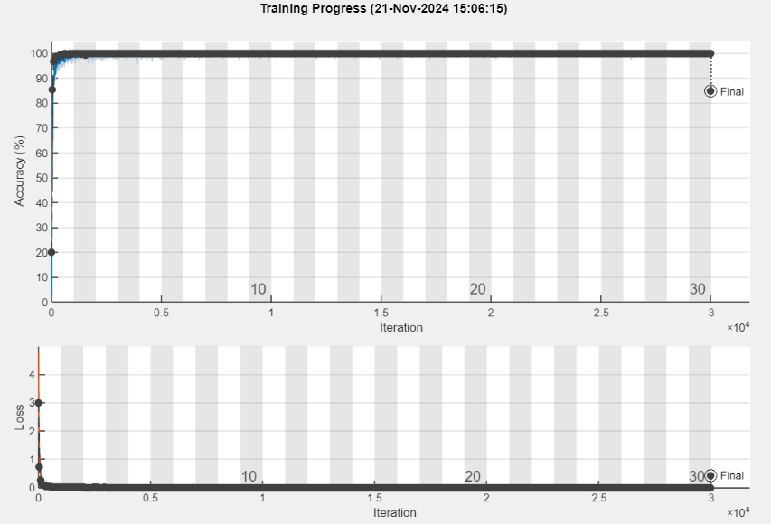
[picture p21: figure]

41

# Rozdział 8 Porównanie wyników

W celu sprawdzenia poprawnego działania dwóch rozwiązań, czyli autorskiej sieci

neuronowej oraz modelu opartego na ResNet50, przeprowadzono testy dokładności

na platformie Raspberry Pi z wykorzystaniem przygotowanej aplikacji. Spodziewanym

rezultatem było uzyskanie lepszych wyników za pomocą douczonej sieci ResNet50 ze względu

na większą liczbę warstw konwolucyjnych.

Po wytrenowaniu dwóch sieci wykonano wykresy obrazujące ich dokładność na zbiorze

walidacyjnym w trakcie procesu uczeniu.

Rys. 8.1 Dokładność przygotowanej sieci

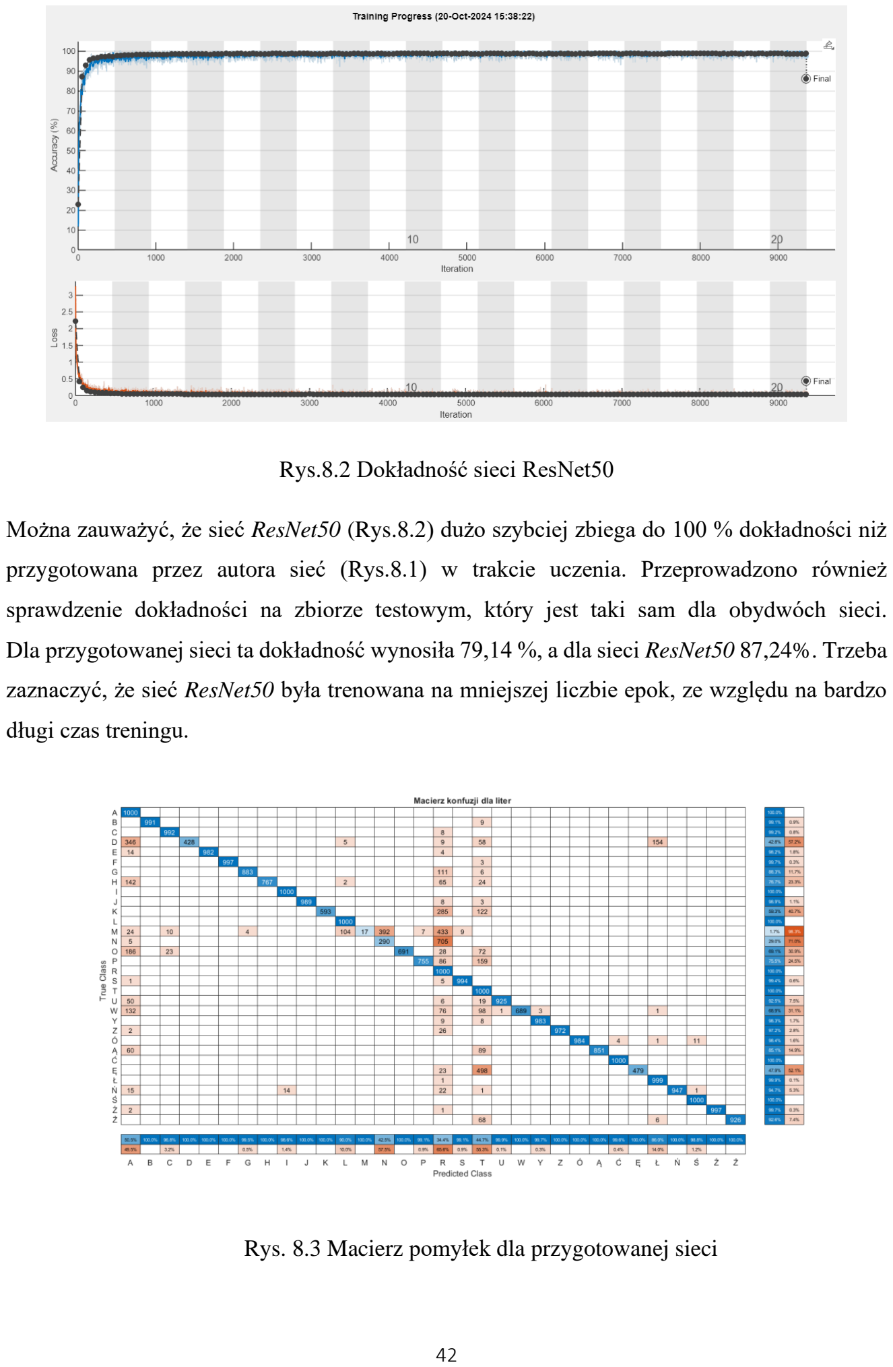
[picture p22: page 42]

42

Rys.8.2 Dokładność sieci ResNet50

Można zauważyć, że sieć ResNet50 (Rys.8.2) dużo szybciej zbiega do 100 % dokładności niż

przygotowana przez autora sieć (Rys.8.1) w trakcie uczenia. Przeprowadzono również

sprawdzenie dokładności na zbiorze testowym, który jest taki sam dla obydwóch sieci.

Dla przygotowanej sieci ta dokładność wynosiła 79,14 %, a dla sieci ResNet50 87,24%. Trzeba

zaznaczyć, że sieć ResNet50 była trenowana na mniejszej liczbie epok, ze względu na bardzo

długi czas treningu.

Rys. 8.3 Macierz pomyłek dla przygotowanej sieci

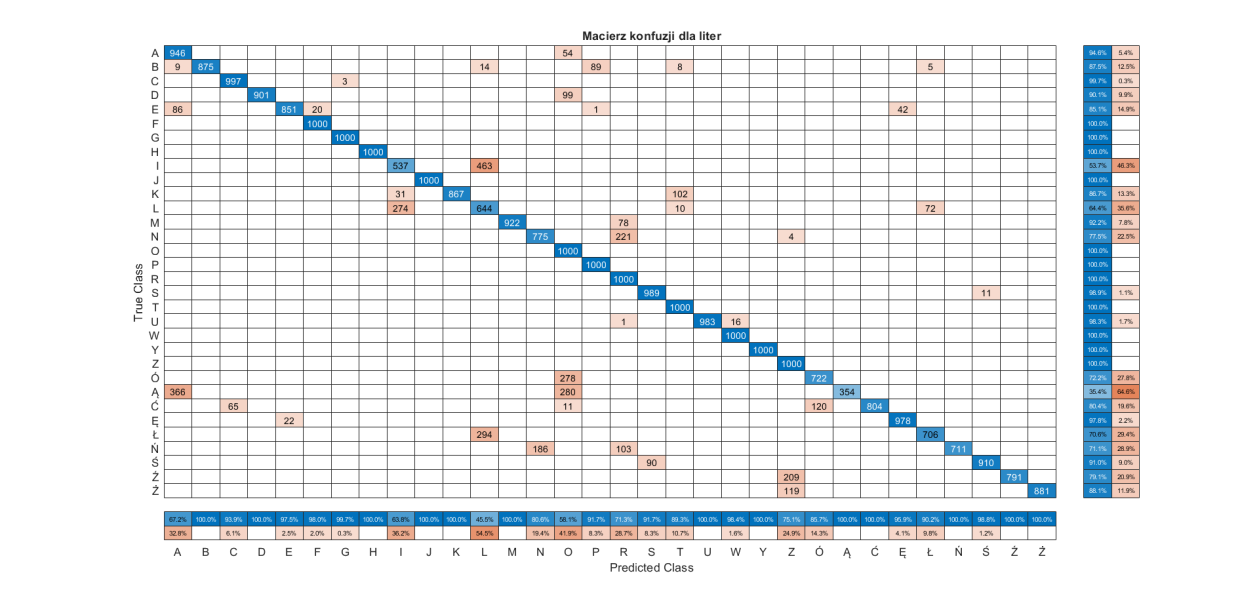
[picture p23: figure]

43

Przygotowano również macierz pomyłek (ang. confusion matrix) przedstawioną

na Rys.8.3, dzięki której można zaobserwować, które litery były najczęściej mylone.

Najrzadziej poprawnie sklasyfikowane litery to „m” i „n” i były one mylone z literą „r”.

Dzieje się tak ze względu na dużo podobieństwo tych znaków do siebie. Również często

myloną literą jest „ę”, gdzie najczęściej była klasyfikowana jako litera „e”. Pozostałe polskie

znaki były w większości klasyfikowane poprawnie.

Taką samą macierz wyznaczono również dla sieci ResNet50 i pokazano na Rys.8.4.

Rys.8.4 Macierz pomyłek dla sieci ResNet 50

Jak się spodziewano wyniki otrzymane z użyciem sieci ResNet50 są dokładniejsze

i klasyfikacja jest istotnie lepsza. Jednak co zaskakujące model ResNet bardziej myli się przy

polskich znakach niż autorska sieć neuronowa. Nie wykazuje jednak cech nadmiernej

klasyfikacji poszczególnych liter. Najrzadziej rozpoznawaną literą jest „ą” i głównie jest

mylone z „a” oraz „o”.

Następnie sprawdzono działanie całego urządzenia bazując na dwóch modelach

wykorzystując platformę Raspberry Pi. W tym celu przygotowano 2 rodzaje tekstów: jeden,

gdzie tekst jest dobrze widoczny z wyraźnymi przerwami (Rys. 8.5) oraz fragment, gdzie litery

są mniejsze bez dużych odstępów (Rys.8.6).

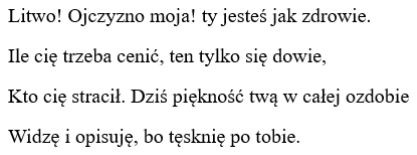
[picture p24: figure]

44

Rys.8.5 Fragment testowy z dużymi odstępami [21]

Wyraźny tekst nie sprawił problemu modelowi ResNet50. Sieć rozpoznała cały tekst

i prawidłowo go przeczytała. Autorskiej sieci neuronowej problem sprawiły jedynie litery „n”.

W słowie „ostatni” oraz „na” zostały rozpoznane jako litera „r”, przez co przekaz fragmentu

jest trochę zaburzony. W przypadku segmentacji obraz został podzielony prawidłowo, a znak

interpunkcyjny w postaci przecinka nie został poddany klasyfikacji.

Rys.8.6 Fragment testowy z małymi odstępami [21]

Początek inwokacji „Pana Tadeusza” autorstwa Adam Mickiewicza sprawił więcej

problemów obydwu sieciom. Segmentacja obrazu została przeprowadzona prawie idealnie,

jednak za jedną literę zostały uznane „st” w wyrazie „stracił”, „rz” w wyrazie „trzeba”, „zd”

w wyrazie „ozdobie” oraz „kn” w wyrazie „tęsknię”. Z tego powodu te połączenia liter nie

mogły być sklasyfikowane poprawnie przez obydwa modele. Autorska sieć neuronowa znowu

nie była w stanie sklasyfikować poprawnie wszystkich liter „n” oraz „m”, które myliła z literą

„r”. Dodatkowo raz litera „p” została pomylona z „t”, obydwa wykrzykniki zostały

sklasyfikowane jako litera „i”, dwie litery „ę” oceniono jako „e” oraz kilka innych pomyłek.

45

Autorski model miał więc dokładność 83,55% na podanym fragmencie. Model ResNet50,

oprócz złej klasyfikacji liter, związanej z nieudaną segmentacją, ocenił zdecydowaną liczbę

liter poprawnie. Nie miał takich problemów z klasyfikacją liter „n” i „m” jak autorska sieć,

jednak napotkał problem przy ocenie niektórych polskich znaków. Mimo tego model miał

dokładność | 92,76%. | Wysokie | dokładności | obydwóch | modeli | są | spowodowane

wykorzystaniem zrzutów ekranu przy sprawdzeniu jakości klasyfikacji sieci, a nie zdjęć

z kamery jak to będzie miało miejsce w ostateczniej wersji projektu.

Zgodnie z oczekiwaniami rezultaty otrzymane dzięki wykorzystaniu modelu

używającego sieć ResNet50 są dokładniejsze szczególnie dla tekstu o mniejszym rozmiarze

znaków. Autorska sieć neuronowa natomiast nie rozpoznała tylko dwóch liter dla tekstu, gdzie

ostępy między literami były większe. Użycie segmentacji opartej o linie konturowe okazało się

bardzo trafne, ponieważ obraz, gdzie odstępy były małe został podzielony bardzo dokładnie.

Główną różnicą pomiędzy obydwoma modelami jest rozmiar obrazu wejściowego, gdzie

w modelu ResNet50 jest dużo większy niż w autorskiej sieci. To sprawia, że model ResNet50

jest w stanie dużo dokładniej rozpoznawać cechy danego obrazu.

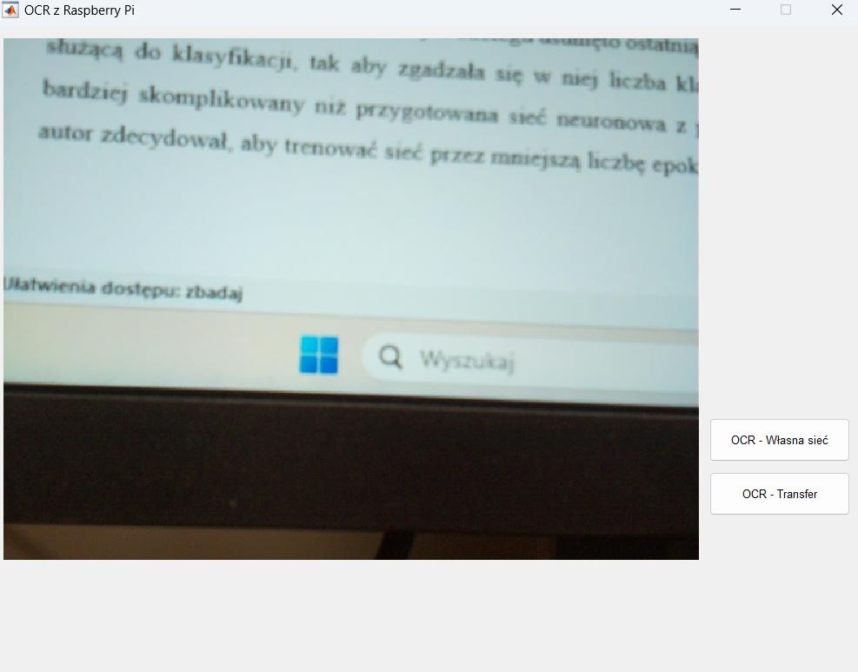
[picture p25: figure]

46

# Rozdział 9 Testy funkcjonalne

W celu usprawnienia procesu testowania urządzenia autor stworzył prostą aplikację,

której główne okno pokazano na Rys.9.1. Interfejs graficzny składa się z aktualnego obrazu

przekazywanego z kamery oraz ma możliwość wyboru rodzaju modelu przeznaczonego

do rozpoznawania tekstu.

Rys.9.1 Interfejs aplikacji do testowania urządzenia

Aplikacja otrzymuje dane z Raspberry Pi poprzez lokalną sieć Wi-Fi i służy tylko

do wizualizacji, co oznacza, że cała logika projektu jest wykonywana na minikomputerze.

Autor wykorzystuje również syntezator systemowy Windows w celu sprawdzenia czy tekst

faktycznie jest dobrze rozpoznawany. GUI zostało całkowicie wykonane w programie

MATLAB.

Przeprowadzono testy funkcjonalne działania urządzenia. W tym celu autor wykonał

zdjęcia fragmentu tekstu pod różnym kątem i oświetleniem (Rys.9.2 – 9.4), aby sprawdzić

dokładność działania urządzenia. Wykonano również testy czasowe, aby oszacować średni czas

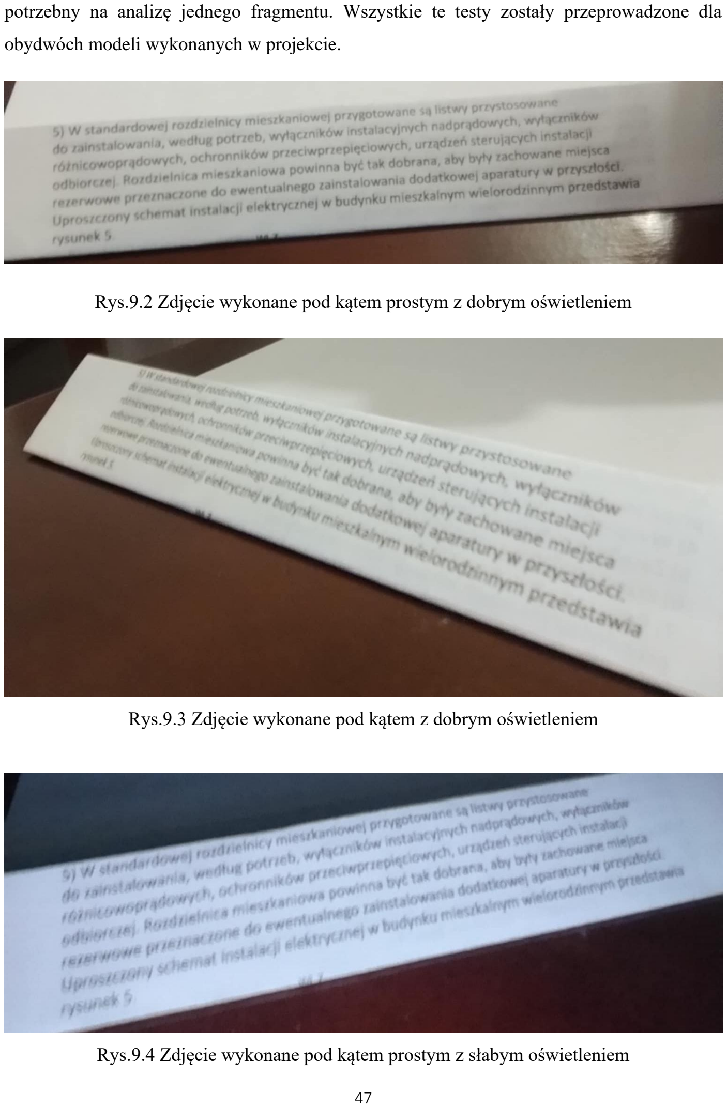
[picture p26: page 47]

47

potrzebny na analizę jednego fragmentu. Wszystkie te testy zostały przeprowadzone dla

obydwóch modeli wykonanych w projekcie.

Rys.9.2 Zdjęcie wykonane pod kątem prostym z dobrym oświetleniem

Rys.9.3 Zdjęcie wykonane pod kątem z dobrym oświetleniem

Rys.9.4 Zdjęcie wykonane pod kątem prostym z słabym oświetleniem

48

Wykonano porównanie działania modelu autorskiego oraz wykorzystującego sieć

ResNet50. Rezultaty, w formie rozpoznanego tekstu, można zobaczyć w Tabeli 9.1.

Tabela 9.1 Porównanie działania modeli przy użyciu Rys.9.2

Rodzaj modelu

Autorski | ResNet50
Sl | W | slardardowej | razdzielricy
rieszkariowej | przygotaw | tistwy
przystosoware | do | zainstalowaria
wedtug | patrzeb | wytączników
instalacyjrych | radprądowych
wyłącznikow | aprądowych,

ochromików pwaciwprzeaitciowych

urządzen | aerujących | irstalacji

odbiorczej Rozazietnica rieszkaniowa

powirna być tak aobrana aby były

zactowane | riejsca | rezarwowe
przeznaczore | da | ewentuatrego

zairstalowaria aodatkowej aparatury

w przysztości Uproszczory scherat

irstalacji etektryczrej w budyrku

rieszkalnyr | wielorodzirnyr

przeastawia rysurek S

SO | W | standordowej | rozdźelnicy

mieszkariowej przygotow sa listwy

przystosoware | do | zalnstalowania
wedtug | potrzeb | wyłoczników
instalacyjnych | nadprodowych
wyłoczników | opradowych,

ochronników pmeciworzepieciowyoh,

urzodzeń | sterujacych | instalacji

odbiorczej Pozdzielnica rieszkaniowa

powinna być tak dobrana aby byty

zachoware | riejsca | reżerwowe
przeznoczone | do | ewentualrego

zainstalowania dodatkowej ąparatury w

przyszłosć | Upromczony | schemat

instalacjl eleitrycznej w budynku

mieszkalryr | wielorodzimym

przedstawla rysunek S

Autorski model osiągnął dokładność 74,84%, gdzie jedynymi relatywnie długimi

słowami, które rozpoznał poprawnie są „aparatury” oraz „odbiorczej”. W pozostałych

przypadkach błędy klasyfikacji to zazwyczaj od 1 do 3 liter na słowo, gdzie najczęściej

mylonymi literami jest „n” z „r”. Model wykorzystujący sieć ResNet50 osiągnął dokładność

86,89%. Ten model rozpoznał poprawnie dużo więcej wyrazów, niż pierwszy, ale za to miał

więcej problemów z klasyfikacją polskich znaków. Dla obydwóch rozpoznanych tekstów

przeprowadzono ich syntezę na dźwięk. Nie wychwycono żadnych niezbieżności między

rozpoznanymi tekstami, a ich reprezentacjami dźwiękowymi.

49

Przeprowadzono również analizę pozostałych dwóch zdjęć, lecz dla nich rezultaty były

niezadowalające. Dokładność klasyfikacji dla Rys.9.3 wynosiła dla autorskiego modelu

21,14%, a dla modelu z siecią ResNet50 24,1%. Rozpoznawane były jedynie znaki znajdujące

się blisko obiektywu kamery. Dla Rys.9.4 obydwa modele rozpoznały jedynie pojedyncze

znaki. Problemem była także segmentacja obrazu, ponieważ większość znaków nie została

wyodrębniona.

Na podstawie serii zdjęć wykonanych pod kątem prostym i z dobrym oświetleniem wykonano również testy czasowe. Średni czas potrzebny do przetworzenia obrazu i klasyfikacji

wszystkich znaków na nim zajął:

- 12,1 s autorskiemu modelowi,
- 20,5 s modelowi używającego sieć ResNet50.

Mimo, że średnio model używający sieci ResNet50 zajmował więcej czasu, jego dokładność

jest o ponad 10 % lepsza od drugiego modelu. Z tego powodu zalecane jest używanie właśnie

modelu ResNet50.

50

# Rozdział 10 Podsumowanie

Podsumowując uważam, że projekt okazał się zasadniczym sukcesem. Ukończono

wszystkie cele zawarte w opisie pracy. W projekcie zawarto opis rzeczywistych rozwiązań

wspomagających osoby niewidome lub niedowidzące, przytoczono definicję zagadnień

związanych z Machine Learningiem. W części poświęconej projektowi dokonano analizy

różnych rodzajów filtrów i metod segmentacji obrazu i wybrano, zdaniem autora, najlepsze

z nich. Wykonano również dwa modele sieci neuronowych do klasyfikacji znaków tekstowych,

na podstawie obrazu z kamery i porównano wyniki ich klasyfikacji. Autor zrealizował również

aplikację ułatwiającą testowanie urządzenia i wykonał obudowę używając druku 3D.

Efektem projektu jest działające urządzenie, które może zostać wykorzystane jako

pomoc dla osoby niewidomej. Jednakże urządzenie w dalszym ciągu może być rozwijane, aby

dało się je zastosować komercyjnie, np. poprzez dodanie szyfrowania kodu, użycie bardziej

trwałego materiału do produkcji obudowy albo wykorzystanie kamery o wyższej

rozdzielczości. Można również dodać moduł oświetleniowy, który pomógłby robić zdjęcia

lepszej jakości. Sam algorytm sieci neuronowej też może zostać ulepszony poprzez dodanie

kolejnych warstw konwolucyjnych i zwiększenie złożoności przeprowadzanych operacji.

Model oparty o Transfer Learning działa dobrze, aczkolwiek autor uważa, że on też mógłby

działać lepiej.

W trakcie pracy nad projektem autor rozwinął swoje umiejętności i wiedzę z zakresu

sztucznej inteligencji, programowania, systemów wbudowanych i wizyjnych oraz

projektowania konstrukcji w 3D. Z tego powodu wybór tematu pracy okazał się być bardzo

dobry uwzględniając kierunek studiów autora.

51

# Bibliografia

[1] Zyrlo LLC, The LyriQ Assistive Reader, https://www.zyrlo.com/ , Ostatnia wizyta:

23.12.2024.

[2] Brian R. Miller, History of the blind, https://www.britannica.com/science/history-of-the-

blind, Publikacja: 17.05.2023.

[3] Envision, Envision Glasses, https://www.letsenvision.com/glasses/home , Ostatnia

wizyta 23.12.2024.

[4] Google Text-To-Speech (TTS), https://cloud.google.com/text-to-speech, Ostatnia

wizyta: 27.12.2024.

[5] S. Rost, "Character Recognition: Image and Video Available: Project One by Stanislav

Rost", 1998, [online] Available: http://web.mit.edu/stanrost/www/cs585pl/pl.html.

[6] | V. | Kwatra, | "Optical | Character | Recognition", | [online] | Available:

http://www.cc.gatech.edu/-kwatra/computer_vision/ocr/OCR.html.

[7] V. Ganapathy and C. C. H. Lean, "Optical Character Recognition Program for Images of

Printed Text using a Neural Network," 2006 IEEE International Conference on Industrial

Technology, Mumbai, India, 2006

[8] | Ryszard | Tadeusiewicz, | Maciej | Szaleniec; „Leksykon | sieci | neuronowych”,

https://www.researchgate.net/publication/294578763_LEKSYKON_SIECI_NEURON

OWYCH_Lexicon_on_Neural_Networks, Wydawnictwo Fundacji „Projekt Nauka”,

Wydanie I Wrocław, Publikacja: 01.2015.

[9] S. J. Pan and Q. Yang, "A Survey on Transfer Learning," in IEEE Transactions on

Knowledge and Data Engineering, vol. 22, no. 10, pp. 1345-1359, Oct. 2010,

[10] J. Hao, "Deep learning-based medical image analysis with explainable transfer

learning," 2023 International Conference on Computer Engineering and Distance

Learning (CEDL), Shanghai, China, 2023

[11] Abhishek, A. Dhankar and N. Gupta, "A Systematic Review of Techniques, Tools and

Applications of Machine Learning," 2021 Third International Conference on Intelligent

52

Communication Technologies and Virtual Mobile Networks (ICICV), Tirunelveli, India,

2021,

[12] C. M. Maheshan & H. Prasanna Kumar „Performance of image pre-processing filters for
noise | removal | in | transformer | oil | images | at | different | temperatures”,

https://link.springer.com/article/10.1007/s42452-019-1800-x, Publikacja: 11.12.2019.

[13] T. Singh and S. Karanchery, "Universal Image Segmentation Technique for Cancer

Detection in Medical Images," 2019 10th International Conference on Computing,

Communication and Networking Technologies (ICCCNT), Kanpur, India, 2019

[14] P. Mimboro, A. Sunyoto and R. S. Kharisma, "Segmentation of Brain Tumor Objects in

Magnetic Resonance Imaging (MRI) Image using Connected Component Label

Algorithm," 2021 International Conference on Advanced Mechatronics, Intelligent

Manufacture and Industrial Automation (ICAMIMIA), Surabaya, Indonesia, 2021,

[15] H. Qu and W. Zhao, "Image Segmentation Edge Detection Technology Based on

Optimization Model," 2023 International Seminar on Computer Science and Engineering

Technology (SCSET), New York, NY, USA, 2023,

[16] Yawei Ma, Jieru Chi, Ran Hu and Guowei Yang, "A new algorithm for characters

segmentation of license plate based on variance projection and mean filter," 2011 IEEE

5th International Conference on Cybernetics and Intelligent Systems (CIS), Qingdao,

China, 2011 [17] Y. Kinoshita and H. Kiya, "Fixed Smooth Convolutional Layer

for Avoiding Checkerboard Artifacts in CNNS," ICASSP 2020 - 2020 IEEE International

Conference on Acoustics, Speech and Signal Processing (ICASSP), Barcelona, Spain,

2020

[18] Z. H. Salsabila, R. R. Nurmalasari and L. Kamelia, "Indonesian Sign Language

Translation System Using ResNet-50 Architecture-Based Convolutional Neural

Network," 2024 10th International Conference on Wireless and Telematics (ICWT),

Batam, Indonesia, 2024

[19] Nitish Kundu „Exploring ResNet50: An In-Depth Look at the Model Architecture and

Code Implementation”, https://medium.com/@nitishkundu1993/exploring-resnet50-an-

in-depth-look-at-the-model-architecture-and-code-implementation-d8d8fa67e46f,

Publikacja: 23.01.2023.

53

[20] Model Raspberry Pi 4B, https://grabcad.com/library/raspberry-pi-4-model-b-1, Ostatnio

odwiedzona: 26.12.2024.

[21] Adam Mickiewicz „Pan Tadeusz”
[22] Dokumentacja Raspberry Pi model 4B, https://botland.com.pl/moduly-i-zestawy-

raspberry-pi-4b/14647-raspberry-pi-4-model-b-wifi-dualband-bluetooth-4gb-ram-

18ghz-5056561800349.html, Ostatnio odwiedzona: 26.12.2024.

[23] Dokumentacja kamery 5MP OV5647, https://botland.com.pl/kamery-do-raspberry-

pi/6850-kamera-arducam-ov5647-5mpx-dla-raspberry-pi-zgodna-z-wersja-oryginalna-

5904422375324.html, Ostatnio odwiedzona: 26.12.2024.

[24] G. Kumar, P. Kumar and D. Kumar, "Brain Tumor Detection Using Convolutional Neural

Network," 2021 IEEE International Conference on Mobile Networks and Wireless

Communications (ICMNWC), Tumkur, Karnataka, India, 2021

[25] Schemat | konwolucyjnej | sieci | neuronowej, | https://bdtechtalks.com/wp-

content/uploads/2019/08/Artificial-Neuron.png, Ostatnio odwiedzona: 04.01.2025.

[26] Y. Cheng and B. Li, "Image Segmentation Technology and Its Application in Digital

Image Processing," 2021 IEEE Asia-Pacific Conference on Image Processing,

Electronics and Computers (IPEC), Dalian, China, 2021

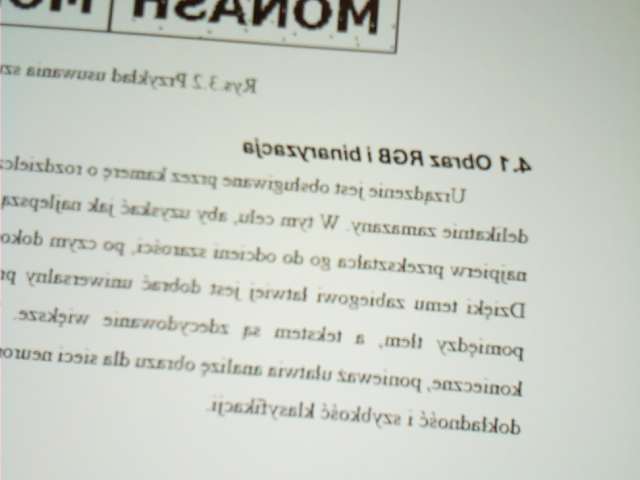
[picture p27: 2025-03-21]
inzynierka/photoforcharts.png

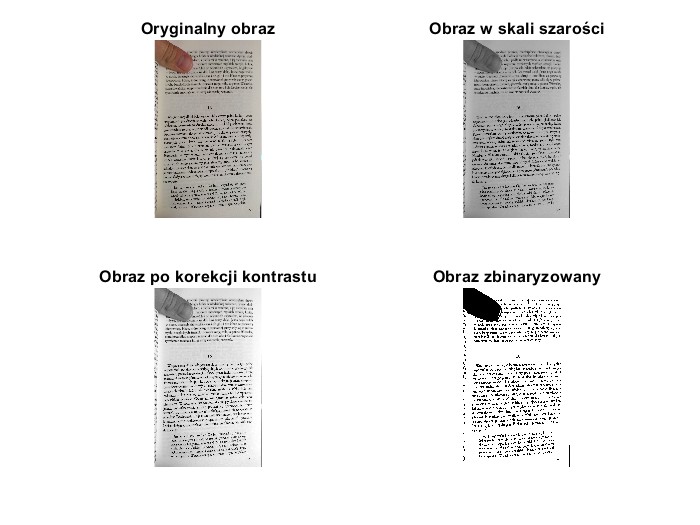
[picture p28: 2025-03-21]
inzynierka/bin.jpg

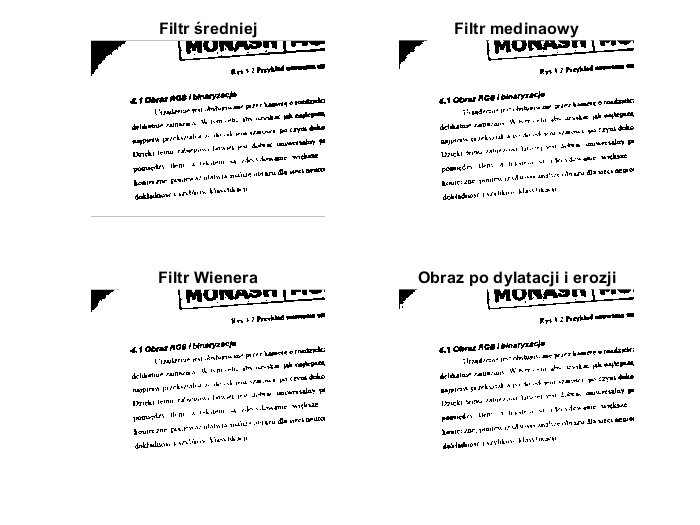
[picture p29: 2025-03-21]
inzynierka/chartsforfilters.png

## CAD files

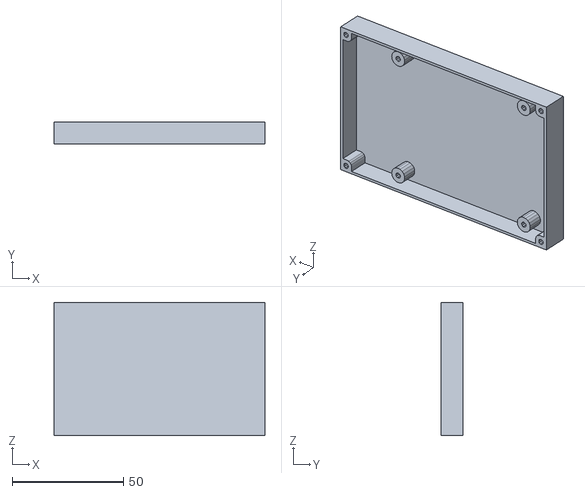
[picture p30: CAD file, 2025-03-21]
inzynierka/dol.stl
95.0 x 10.0 x 60.0

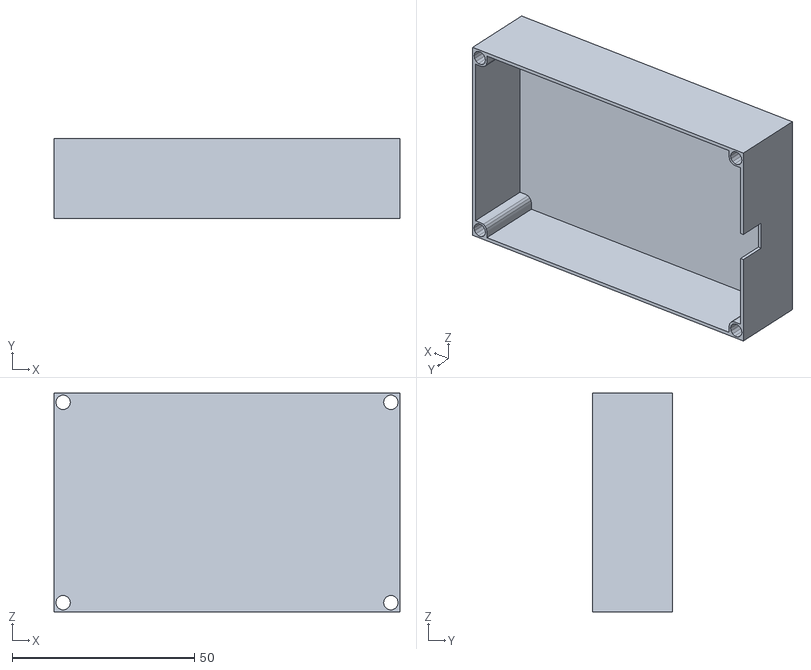
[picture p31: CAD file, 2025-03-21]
inzynierka/góra.stl
95.0 x 22.0 x 60.0

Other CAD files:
inzynierka/calosc.iam
inzynierka/dol.dwg
inzynierka/dol.ipt
inzynierka/góra.ipt

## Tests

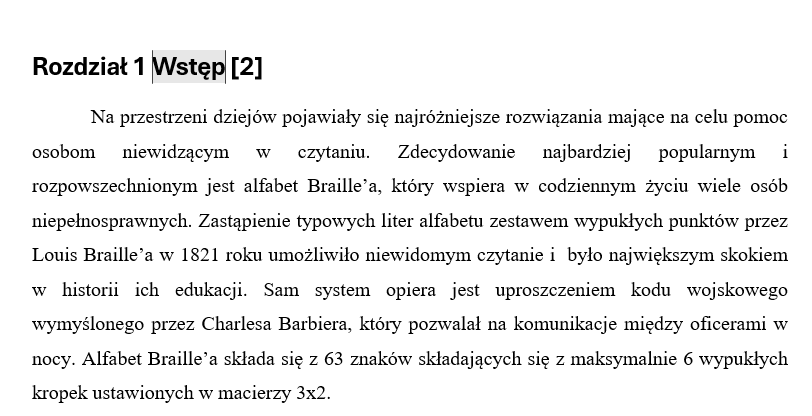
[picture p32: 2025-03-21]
inzynierka/test.png
